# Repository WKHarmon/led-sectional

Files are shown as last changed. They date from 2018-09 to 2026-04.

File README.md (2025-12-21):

# LED Sectional

A WiFi-connected LED display for aviation sectional maps that shows real-time flight conditions at airports using color-coded LEDs.

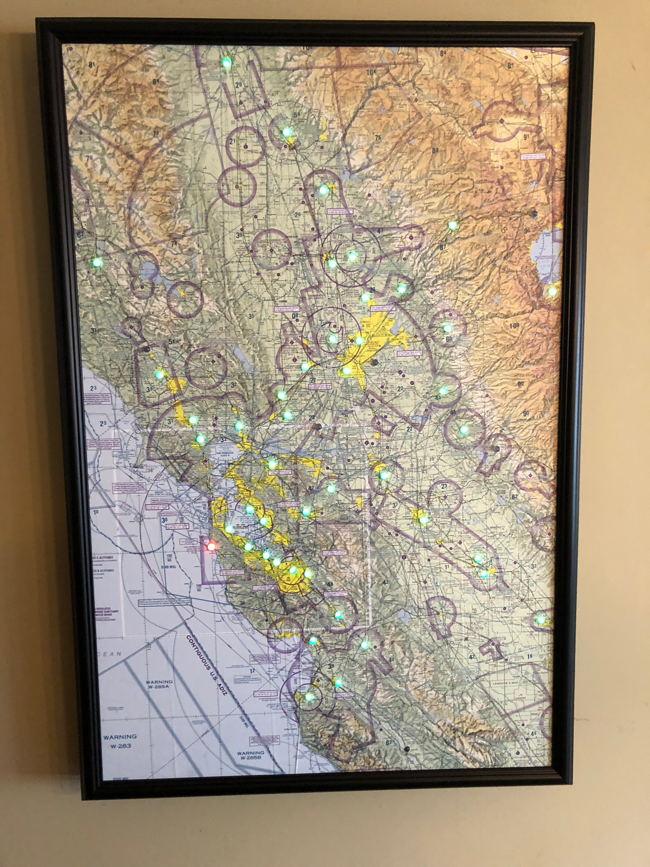
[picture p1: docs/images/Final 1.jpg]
LED Sectional Example


## What It Does

The LED Sectional automatically fetches current weather data (METARs) from aviationweather.gov and displays flight conditions on your sectional map:

| Color | Meaning |
|---|---|
| Green | VFR - Clear skies, good visibility |
| Blue | MVFR - Marginal conditions |
| Red | IFR - Instrument conditions |
| Magenta | LIFR - Low IFR, poor conditions |
| Yellow | High Winds - VFR with winds over 25 knots |
| White Flash | Thunderstorms reported |
| Off | No data available |

Weather updates automatically every 15 minutes.

## What You Need

### Hardware

- **Controller board** - ESP8266-based (Wemos D1 Mini Lite recommended), or purchase a [pre-made kit](docs/kit.md)
- **LED string** - WS2811 or WS2812 LEDs (one per airport)
- **Power supply** - 5V DC, sized for your LED count
- **USB cable** - For initial setup (must support data, not charge-only)

### Your Map

You'll need a framed sectional chart with holes drilled at each airport location. See the [full build guide](docs/index.md) for detailed instructions on creating your map.

## Setup

### Step 1: Install the Firmware

1. Visit the [LED Sectional Configuration Tool](https://led-sectional.kyleharmon.com/configure/)
2. Connect your controller via USB
3. Click the **Firmware** tab
4. Click **Install Firmware** and follow the prompts

### Step 2: Connect to WiFi

After installing firmware, the controller needs your WiFi credentials:

1. Keep the USB cable connected
2. In the Configuration Tool, click **Connect**
3. Go to the **WiFi** tab
4. Enter your network name and password
5. Click **Save** - the device will reboot and connect

**Note:** The controller only works with 2.4 GHz WiFi networks.

### Step 3: Add Your Airports

1. In the Configuration Tool, go to the **Airports** tab
2. Add airports in order matching your LED string (LED 1 first, LED 2 second, etc.)
3. Use standard ICAO codes (e.g., KSFO, KJFK, KORD)
4. Click **Save** to upload to the device

**Special codes:**
- `NULL` - Skip an LED (leave it off)
- `VFR`, `MVFR`, `IFR`, `LIFR`, `WVFR` - Legend LEDs that always show that color
- `WBNK` - Wind blink demo - alternates between green and yellow (requires "Alternate Colors" setting enabled)

### Step 4: Mount and Enjoy

Disconnect USB, connect your 5V power supply, and mount your sectional!

## Troubleshooting

### LEDs aren't lighting up

- Check that your power supply is 5V and has enough current for your LED count
- Verify the data wire is connected to the correct pin (GPIO 14 / D5 by default)
- Make sure the LED string and controller share a common ground

### Can't connect via Web Serial

- Use Chrome, Edge, or Opera (Safari and Firefox don't support Web Serial)
- Try a different USB cable - some cables only carry power, not data
- Close any other programs that might be using the serial port

### WiFi won't connect

- Confirm your network is 2.4 GHz (5 GHz is not supported)
- Double-check the password
- Move the controller closer to your router during setup

### Some airports show no color

- The airport may not have recent METAR data
- Verify the ICAO code is correct at [aviationweather.gov](https://aviationweather.gov/)

## Adjusting Settings

In the Configuration Tool's **Settings** tab, you can adjust:

- **Brightness** - LED brightness level (0-255)
- **Wind Threshold** - Wind speed that triggers yellow color (default: 25 knots)
- **Lightning Animation** - Enable/disable flashing for thunderstorms
- **High Wind Indication** - Enable/disable yellow for high winds
- **Light Sensor** - Enable automatic brightness based on room lighting (requires additional hardware)

### Home Assistant Integration

The LED Sectional can integrate with Home Assistant for smart home control. Once configured, your sectional appears as a light in Home Assistant where you can:

- Turn the display on/off
- Adjust brightness
- Include in automations (e.g., dim at night, turn off when away)

To set up, go to **Settings > Advanced Settings** in the Configuration Tool and enable MQTT. Enter your Home Assistant's MQTT broker address and credentials. The device will automatically appear in Home Assistant via MQTT Discovery.

## More Information

- [Full Build Guide](docs/index.md) - Detailed instructions for building your sectional
- [Kit Information](docs/kit.md) - Pre-made electronics kit
- [Contributing & Development](CONTRIBUTING.md) - For developers who want to modify the code

## Acknowledgments

- Inspired by [this Reddit post](https://www.reddit.com/r/flying/comments/7avr8q/flight_conditions_sectional_wall_art_thing/) and [Dylan Rush's blog](http://blog.dylanhrush.com/2017/07/live-sectional-map.html)
- Weather data from [aviationweather.gov](https://aviationweather.gov/)
- Web flashing powered by [ESP Web Tools](https://esphome.github.io/esp-web-tools/)

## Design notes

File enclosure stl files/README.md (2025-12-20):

# LED Sectional Enclosure
These are STL files used to 3D print a small enclosure for the [PCB used in this project](https://github.com/WKHarmon/led-sectional/tree/main/pcb%20files). The board is attached to the enclosure using 3 short M2 screws.

I've published this on Seeed Studio's [Fusion Gallery](https://www.seeedstudio.com/LED-Sectional-Board-g-1207811) for easy making.

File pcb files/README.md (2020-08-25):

# PCB Files
Originally this project used a WEMOS D1 Mini; however, to make assembly a bit easier the PCB now has all the components placed on the PCB directly, including an ESP8285 microcontroller. All of the SMD components are from the parts library that [jlcpcb.com](https://jlcpcb.com) can assemble directly for cheap. The files in this folder are:

* LED Sectional PCB - EasyEDA.json - PCB design file for import into EasyEDA.
* LED Sectional - Gerbers.zip - PCB production files that should be usable by any PCB manufacturer.
* LED Sectional - BOM.csv - All of the components used in the board design.
* LED Sectional - Centroid.csv - Pick and place file for assembly of the SMD components.

If assembling through jlcpcb.com, it's still necessary to solder all of the through hole components like the micro USB, power, and LED connectors. Other assembly fabs can handle the thru-hole components, but most charge significantly more for the via-in-pads that are used in the design.

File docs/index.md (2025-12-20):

LED Sectional
=============
* [LED Sectional](#led-sectional)
* [Pictures](#pictures)
* [Things you'll need](#things-youll-need)
    * [Electronics](#electronics)
        * [LED Sectional Kit](#led-sectional-kit)
        * [Buying a la carte](#buying-a-la-carte)
    * [Map and Frame](#map-and-frame)
    * [Tools](#tools)
* [Software](#software)
* [Assembly](#assembly)
    * [Soldering and Wiring](#soldering-and-wiring)
    * [Mounting the sectionals](#mounting-the-sectionals)
    * [Drilling](#drilling)
    * [Glueing LEDs](#glueing-leds)
* [Final Details](#final-details)

This project is adapted from a few other very similar ones:
* [Live sectional map](http://blog.dylanhrush.com/2017/07/live-sectional-map.html)
* [Flight conditions sectional wall art thing](https://www.reddit.com/r/flying/comments/7avr8q/flight_conditions_sectional_wall_art_thing/)
* [Creating a METAR map](https://pplaviationuk.wordpress.com/creating-a-metar-map/)

There were small gaps in the how-to details for some of them so I figured it might be helpful to fully document how I did it. I also opted to use a microcontroller rather than a Raspberry Pi, so mine is different in that way too.

# Pictures
Here are a few pictures of the final product:
Final Product
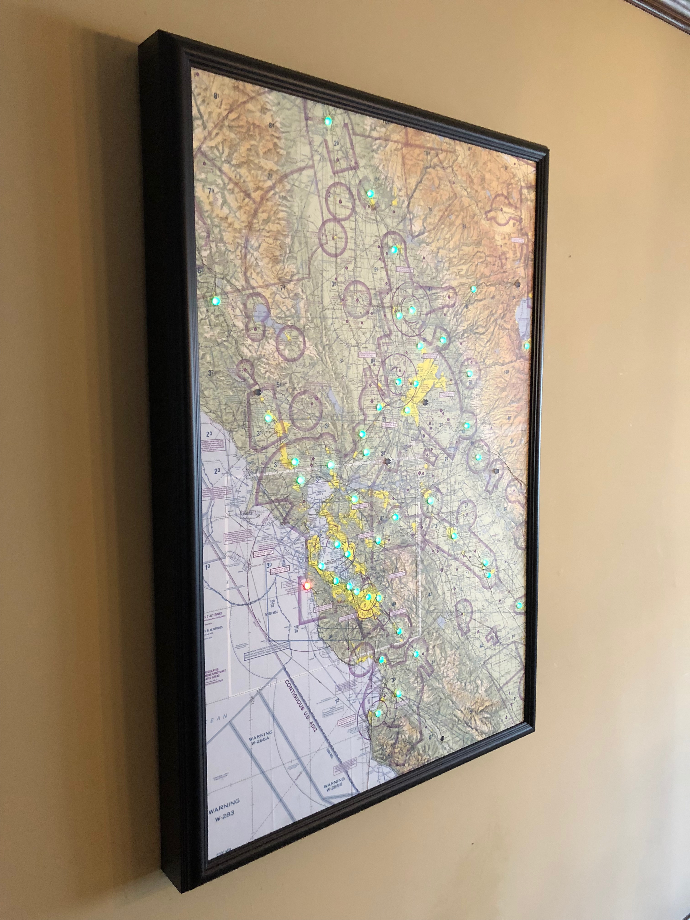
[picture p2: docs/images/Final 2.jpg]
Final Product

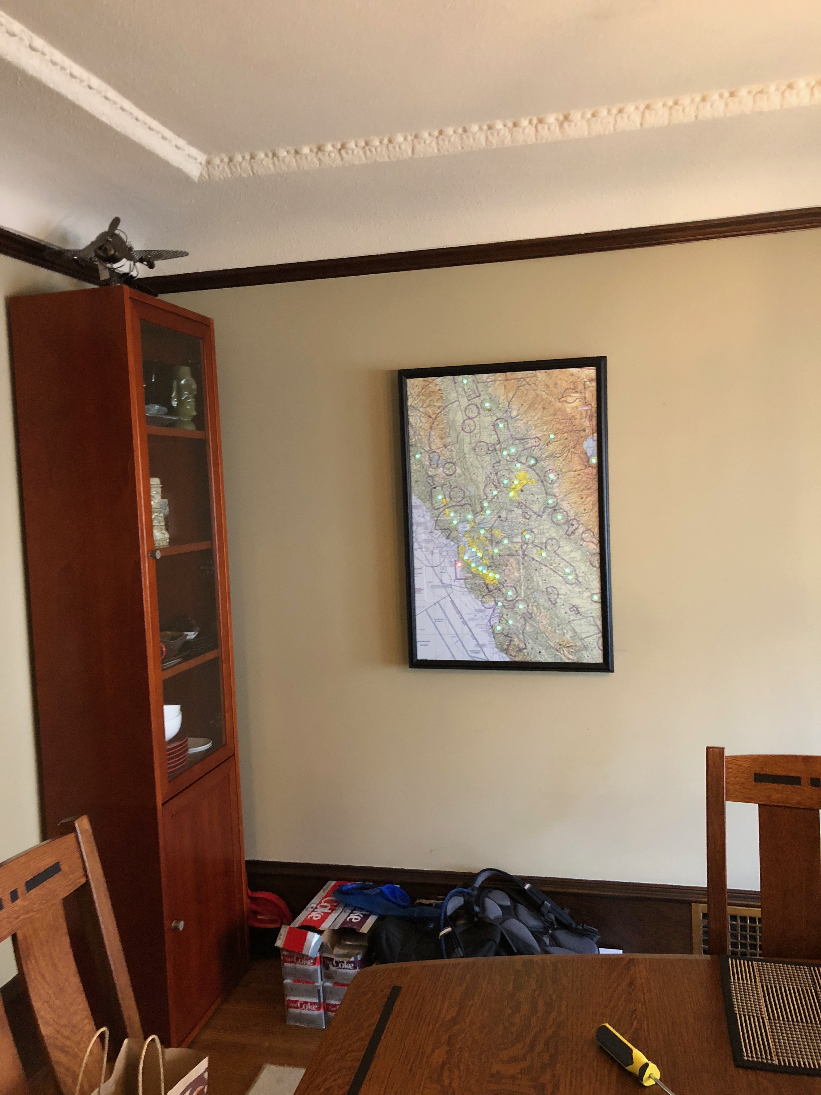
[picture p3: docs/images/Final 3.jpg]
Final Product


# Things you'll need
The materials themselves are pretty cheap--you should be able to get everything you need aside from the frame for less than $100. The frame cost will vary depending on how big you want to make the sectional. The tools may add some cost if you don't already have what you need.

## Electronics
### LED Sectional Kit
I originally wrote this guide with instructions on how to buy all of the electronic components on Amazon, but now I have a kit available that contains all of the electronics except for the power adapter and the LED strands themslves. The kit is significantly cheaper than buying each of the components a la carte since most of the components come in large quantities.

[Click here to find out more information about the kit.](kit.md)

The Amazon links from the original how-to are below in case you'd enjoy doing everything yourself.

### Buying a la carte
I've linked to Amazon for most of the electronic items. You should be able to buy them for cheaper and in smaller quantites from Aliexpress or another similar store if you're willing to wait for the shipment. (In the interest of full disclosure, the Amazon links do have my affiliate tags, but I'm not really trying to make any money here.)
* [WEMOS D1 Mini Lite](https://www.aliexpress.com/store/product/WEMOS-D1-mini-Lite-V1-0-0-WIFI-Internet-of-Things-development-board-based-ESP8285-1MB/1331105_32795857574.html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)
    * If you have time to wait for the shipment, support them and buy from the official store, but [this version on Amazon](https://amzn.to/2R4Pjio) also worked fine.
    * The non-Lite version will work fine, and this code should be pretty adaptable to any Arduino-compatible board with WiFi.
* 3.3V to 5V Level Shifter
    * [WeiMeet 4 Channel Level Converter](https://amzn.to/2R50OGu) - These are what I originally used (and will document here), but they're considered to be a bit slow. You may run into problems if you have a ton of LEDs.
    * [74HCT245](https://www.aliexpress.com/item/10PCS-SN74HCT245N-DIP20-SN74HCT245-DIP-74HCT245-74HCT245N-DIP-20-new-and-original-IC/32537892034.html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) are faster and are what I use in the kit.
* [WS2811 LED Strand(s)](https://amzn.to/2BsGVzj)
* [5V DC Power Supply](https://amzn.to/2EE5Oft) - This is more power than you really need--you could get a smaller one if you'd prefer.
* [DC Barrel Connectors](https://amzn.to/2Gu7aeh)
* [Solid Core Hookup Wire](https://amzn.to/2BwFLD3) - 22G worked well for me
* [3cm x 7cm PCB](https://amzn.to/2GudB15) - This has a bunch of PCBs, I'm sure there's a cheaper opton. Other sizes will work, but these fit nicely into a small project enclosure.
* Optional: [80mm x 50mm x 20mm Project Enclosure](https://amzn.to/2ShrLUw)
* Optional: 3-pin [JST-XH Connectors](https://amzn.to/2SbjpOi) and [JST-SM Connectors](https://amzn.to/2LoXkJy) if you want a interface between the microcontroller and the LED strand(s)
* Optional: [Velcro](https://amzn.to/2BssRpr) to affix the power supply and controller to the board
* Optional components recommended by NeoPixels that I didn't add:
    * 1000 µF, 6.3V or higher capacitor - put this between the 5v and Ground on the power adapter to mitigate spikes on power-on
    * 220 Ohm resistor - put this on the data wire between the level shifter HV1 pin and the data wire on the connector to the LED strand to also mitigate power spikes

## Map and Frame
**You'll also need either:**
* Sectional(s) from the FAA - remember that they're two sided so you may need two to get full coverage
* 3/8" Foamcore or [Hard Tempered Board](https://www.homedepot.com/p/Hardboard-Tempered-Common-1-8-in-x-2-ft-x-4-ft-Actual-0-125-in-x-23-75-in-x-47-75-in-7005015/202088786) or MDF
    * I used the board in my first map, but found foamcore to be much easier to work with on one I made for a friend.
* [3M Super 77 Spray Adhesive](https://www.homedepot.com/p/3M-16-7-oz-Super-77-Multi-Purpose-Spray-Adhesive-77-24VOC30/301619194)
* [SP8 Picture Frame](https://www.pictureframes.com/Custom-Frames/Canvas-Ready-Wood-Picture-Frames/SP8-black-wood-canvas-frame)
    * This is one of the only super-deep frames I've seen that are easily orderable online.
* Optional: [PVA Adhesive](https://amzn.to/2EC5qhn) if you have a seam between sectionals

**OR**

* Have a [digital file](https://www.faa.gov/air_traffic/flight_info/aeronav/digital_products/vfr/) of the sectional printed and mounted on foamcore at [PictureFrames.com](http://www.pictureframes.com). If you do this, be sure to maintain the 300 ppi from the original file in order to keep the sectional to scale (assuming you want that at least).
    * Use the [SP8 Picture Frame](https://www.pictureframes.com/Custom-Frames/Canvas-Ready-Wood-Picture-Frames/SP8-black-wood-canvas-frame) for plenty of depth. The [SP2 Picture Frame](https://www.pictureframes.com/Custom-Frames/Canvas-Ready-Wood-Picture-Frames/SP2-black-wood-canvas-frame) also works pretty well, but the wires may rub against the wall.

## Tools
Here are the tools you'll need. I've provided links to the ones I use, but any set of good tools will work.
* [Glue gun](https://amzn.to/2V492Om) with plenty of [glue](https://amzn.to/2Sby6RA)

If you used foamcore backing:
* [Foamboard Hole Drill](https://amzn.to/2VIc7Du) (You'll use the smallest one in the set.)

If you used wood backing:
* Drill with a 7mm drill bit

If you went the a la carte route for the electronics, you'll also need:
* [Soldering iron](https://amzn.to/2BwFUGB) and solder
* [Wire stripper](https://amzn.to/2BzBWg6)
* Optional: [Crimper for JST connectors](https://amzn.to/2S5a1fi)

# Software

## Web-Based Configuration (Recommended)

The easiest way to set up your LED Sectional is using the **[LED Sectional Configuration Tool](configure/)**. This browser-based tool allows you to:

* **Flash firmware** directly from your browser - no software installation required
* **Configure WiFi** by entering your network credentials
* **Set up your airport list** with a drag-and-drop interface
* **Adjust settings** like brightness, wind thresholds, and lightning effects
* **Connect to Home Assistant** for smart home control (optional)

Just connect your controller via USB, open the tool in Chrome, Edge, or Opera, and follow the on-screen instructions.

## How It Works

The program uses standard definitions for VFR, MVFR, IFR, and LIFR, but also shows yellow if an airport is VFR with winds greater than 25 knots, and airports will flash white if there are thunderstorms in the area.

On power on, all LEDs will show orange initially. Once the controller is connected to the WiFi network, they'll turn purple, and then they'll show the airport colors once the data is downloaded and parsed. LEDs for airports that have not reported weather in the last 3 hours, or that don't have a clear flight category will be turned off. Weather is updated every 5 minutes.

## Manual Setup (Advanced)

If you prefer to program the board manually, the source code is available at [https://github.com/WKHarmon/led-sectional](https://github.com/WKHarmon/led-sectional). See the [CONTRIBUTING.md](https://github.com/WKHarmon/led-sectional/blob/main/CONTRIBUTING.md) file for development instructions.

# Assembly
## Soldering and Wiring
The following section is only necessary if you went the a la carte route.

The Wemos D1 Mini Lite can accept 5V as input voltage, but the GPIO pins run at 3.3v. The WS2811 LED strand is expecting 5V on the data line, so it is necessary to convert the GPIO 3.3v to the WS2811 5V using a logic level shifter. (In some cases it may work without the shifter, but using one is the safer bet.) Below is a breadboard diagram for wiring it all up:

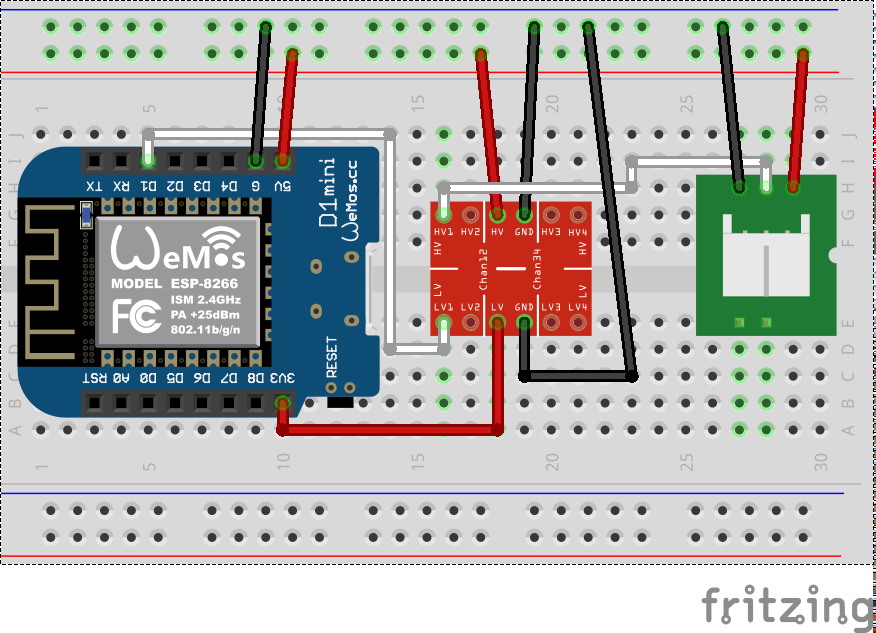
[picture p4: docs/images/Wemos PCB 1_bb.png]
Breadboard Diagram


I've diagramed on a breadboard for simplicity, but I used a 3cm x 7cm PCB. In the diagram, the (optional) JST-XH connector on the right goes to the WS2811 LED strand. If you don't want to bother with the connector, you can just solder the wires from the LED strand to the PCB.

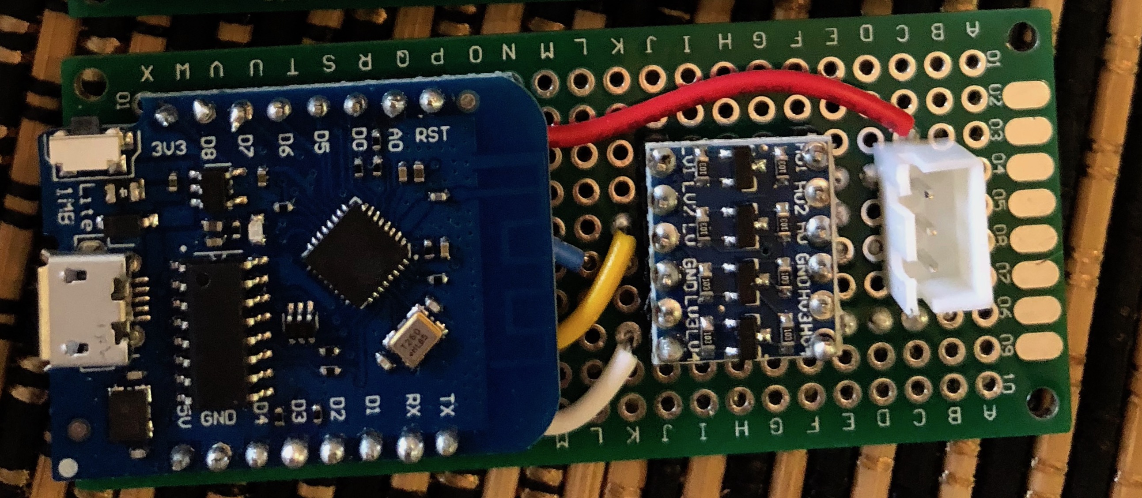
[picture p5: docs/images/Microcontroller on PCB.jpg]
Controller on PCB


 If you have a smaller number of LEDs on your map, it may be possible to power the LED strand from the Micro USB port on the Wemos D1 Mini rather than connecting an external power supply. No wiring changes are necessary, but be sure to not connect an external power supply when the Micro USB port is connected. Also be aware that the Wemos D1 Mini has a 0.5A fuse on the 5V line so it would need to be a really small number of LEDs.	

The data flow on the WS2811 strand is directional. In the LED pixel itself, the PCB will be marked with an arrow on one side. That arrow indicates the input side of the pixel. Connect the microcontroller to the side of the strand such that the wires from the controller are connected to the input side of the pixel (with the arrow), matching the 5V, Data, and Ground lines on the strand to those on the controller.

The WS2811 LED strand has pigtails for injecting power on the ends of the strand as well. Solder a DC barrel connector for power to the pigtails nearest the microcontroller. The microcontroller will receive power from its conenction to the LED strand.

Once I had it all connected up, I created a small pigtail with a JST-XH connector on one side and a JST-SM connector on the other side (which matches the connectors that came with the LED strand) to make it easy to attach and detach the LED strand, then I put it in an enclosure box.

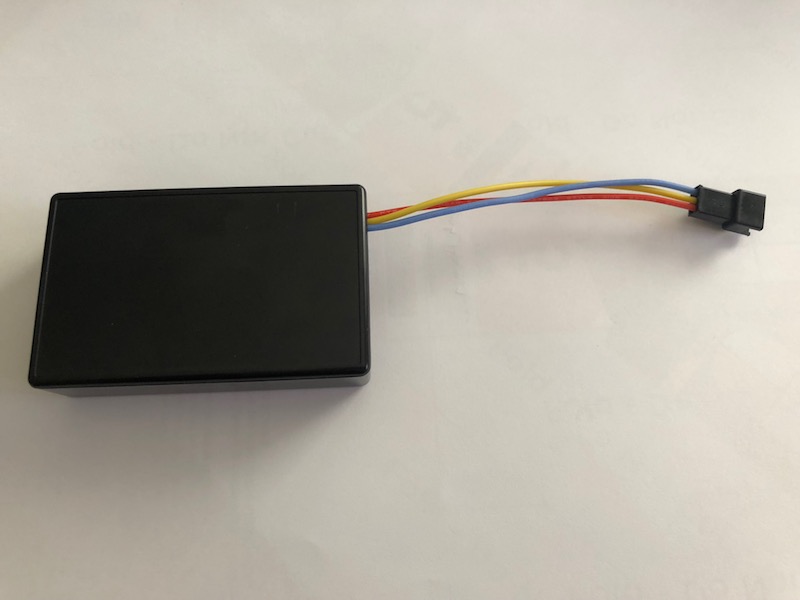
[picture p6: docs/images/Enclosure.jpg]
Enclosure


## Mounting the sectionals
This section is only necessary if you bought actual sectionals and didn't take the shortcut and have a sectional printed and pre-mounted.

When I bought the Hard Tempered Board noted above, I had Home Depot cut it to the desired size. The combined halves of the San Francisco sectional were just over 36" high, and the board itself was 24" wide, so I just decided to use that width.

I cut off the bottom white space of the northern sectional, then I taped the sectionals at the seam using scotch tape, and measured which 24" of the sectional width I actually wanted. I then put the board on top of the sectional and used an Exacto knife to cut off the excess parts of the sectional, but leaving about 1" on each side of the sectional just in case I didn't get it perfectly centered when glueing.

Next, I sprayed the shiny side of the board with the 3M Spray Adhesive, waited about a minute per the directions, and then laid the sectional flat on the board so it would adhere. I used a ruler to flatten out any spots that were not flat.

Once the glue was dried, I cut off the excess parts of the sectional using an exacto knife, and then glued the flap created by the seam between the two sectionals using PVA Adhesive.

## Drilling
**Important: Don't use ForeFlight to determine where METARs are available.** ForeFlight aggregates several sources of weather data together, and contains several airports that are not available via the aviationweather.gov API. I suggest using the METAR map at aviationweather.gov to determine where to drill.

The Foamboard Holl Drill makes super clean cuts and is the perfect size for the LEDs, so I highly recommend grabbing that set if you used foamcore backing and drilling using them.

On my first board I used wood backing, which was quite a bit more challenging. I used a 7mm drill bit to drill through the sectional and the backing board together. This resulted in some holes that weren't super clean.

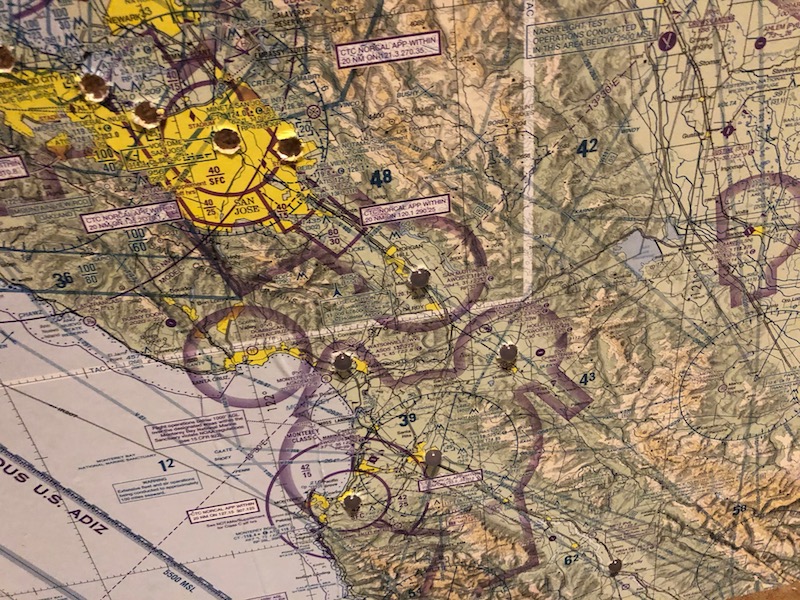
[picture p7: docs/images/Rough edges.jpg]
Rough Edges


I specifically wanted my LEDs to stick out, but if you don't then adjusting the drill bit size and using a countersink bit would allow you to align them with the front of the board.

After I drilled, I then took a file and an exacto knife to clean up the edges to make it look significantly better.

## Glueing LEDs
Once all of the holes were drilled, I rough fit the LEDs throught he holes in the back to try to find the optimal routing. IT's not important what order they're in yet--I'm just trying to waste the fewest LEDs. Once I figured it out, I started gluing a few at a time using the hot glue gun.

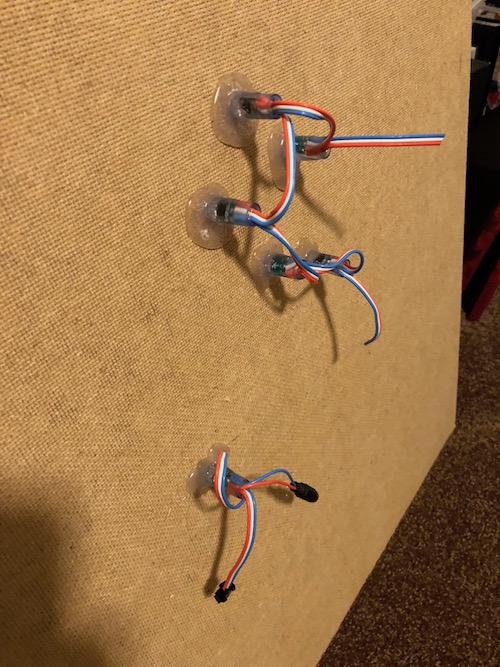
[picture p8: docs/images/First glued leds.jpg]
First Glued LEDs


In the picture you can see that I cut the strand because the next LED in the strand was too far from the previous one, but eventually I realized that LEDs are cheap, so it is much easier to just leave the LEDs on the strand and not use them than to cut the strand and splice in a jumper. The final product looked like this:

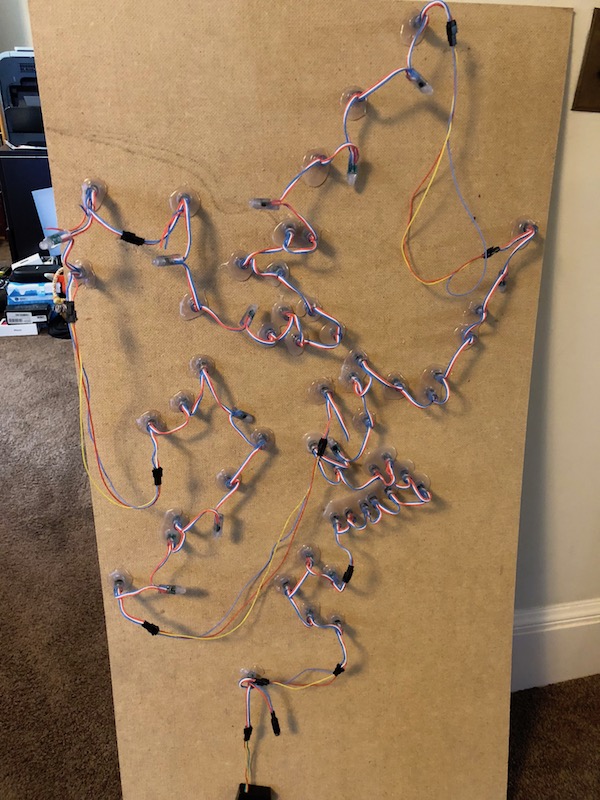
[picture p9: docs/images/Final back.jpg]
Final Back


# Final Details
Because I don't have good tools or really any skills with woodworking, I purchased a frame from [http://www.pictureframes.com](https://www.pictureframes.com/Custom-Frames/Canvas-Ready-Wood-Picture-Frames/SP8-black-wood-canvas-frame). Their SP8 frame has 2 1/4" of depth, which is plenty to contain the electronics. For my 24"x36 1/2" project, it cost me about $120 shipped for the frame, and it came fully assembled with mounting hardware (but no glass), which I thought was a pretty good details.

I mounted the map on a place on my wall previously had a wall sconce light, so I was able to re-use the existing power rather than running new power or running a cable.

Enjoy!

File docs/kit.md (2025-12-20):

# LED Sectional Kits
On the [/r/flying subreddit](https://www.reddit.com/r/flying) there was a [great deal of interest](https://www.reddit.com/r/flying/comments/a4yb83/aviation_nerd_jackpot/ebiscca/) in a simple kit for the electronic components that could be used to create a [LED Sectional](index.md). Because of that, I've created a simple kit to help kickstart the process.

## Ordering

There are three different ordering links depending on how you'd like your kit configured.
1. [Buyer programs](https://www.paypal.com/cgi-bin/webscr?cmd=_s-xclick&hosted_button_id=CFKGLG5F2ETDW)
    * The kit will arrived programmed with a LED test program so you can ensure the strand is working properly. You'll need to program it for your map using the instructions located [here](index.md#software). You will need a high-quality Micro USB cable in order to program the board.
2. [Buyer programs, with an included ambient light sensor](https://www.paypal.com/cgi-bin/webscr?cmd=_s-xclick&hosted_button_id=67RASVCG8DK5A)
    * This includes an added ambient light sensor so the map can be programmed to automatically turn off when the ambient lights are off. I would recommend ONLY adding the light sensor if you plan to put the map in a room where the light will be disruptive at night as this will not significantly impact power usage.

**An important note:** *These kits are provided without support.* If there are any hardware problems with the kit you receive please reach out and I'll be happy to help, but you should only buy it if you're comfortable with the instructions and troubleshooting on your own. I'm not trying to make a profit on these so I am selling these very close to cost. As you can imagine, there's a fair bit of effort involved in putting them together. If you like your kit once you receive it, I would appreciate it if you considered giving a tax deductible donation to the [Upwind Foundation](https://www.upwindscholarship.com/). We're having a bit of a contest to see who can raise the most, so please do mention my name (Kyle Harmon) if you donate.

## About the Kit
The kit includes the following:
* A custom PCB that includes the following:
    * An ESP8285 microcontroller and components and interfaces that replicate a [WEMOS D1 Mini Lite](https://docs.wemos.cc/en/latest/d1/d1_mini_lite.html) development board.
    * The following additional components included for connectivity and to comply with [Adafruit's Best Practices](https://learn.adafruit.com/adafruit-neopixel-uberguide/best-practices):
        * [330 Ohm Resistor](https://lcsc.com/product-detail/Chip-Resistor-Surface-Mount_UNI-ROYAL-Uniroyal-Elec-0603WAF3300T5E_C23138.html)
        * [1000 µF Capacitor](https://lcsc.com/product-detail/Aluminum-Electrolytic-Capacitors-SMD_Lelon-VEJ102M1ATR-1010_C134756.html)
        * [3-pin JST XH Connector](https://lcsc.com/product-detail/Wire-To-Board-Wire-To-Wire-Connector_BOOMELE-Boom-Precision-Elec-XH-3A_C2316.html) to connect LEDs
        * [5-pin JST XH Connector](https://lcsc.com/product-detail/Wire-To-Board-Wire-To-Wire-Connector_BOOMELE-Boom-Precision-Elec-XH-5A_C2318.html) (if shipped with a light sensor) connected to the i2c bus for a TSL2561 light sensor
        * 2x [TS-1187A-B-A-B tacticle switches](https://lcsc.com/product-detail/Tactile-Switches_XKB-Connectivity-TS-1187A-B-A-B_C318884.html), one connected to the reset switch and one ("PROGRAM") connected to GPIO12 (currently unused in the sketch)
        * [M74VHC1GT126DF1G logic level shifter](https://lcsc.com/product-detail/Logic-Buffers-Drivers-Receivers-Transceivers_ON-Semiconductor-ON-M74VHC1GT126DF1G_C150237.html) to shift 3.3v logic to 5v logic for LEDs
        * [2.1mm x 5.5mm DC Barrel Jack](https://www.digikey.com/product-detail/en/cui-inc/PJ-037A/CP-037A-ND/1644545)
* Custom 3D printed case
* JST-XH to JST-SM cable for connecting LEDs.

Here's are some pictures of what you get:
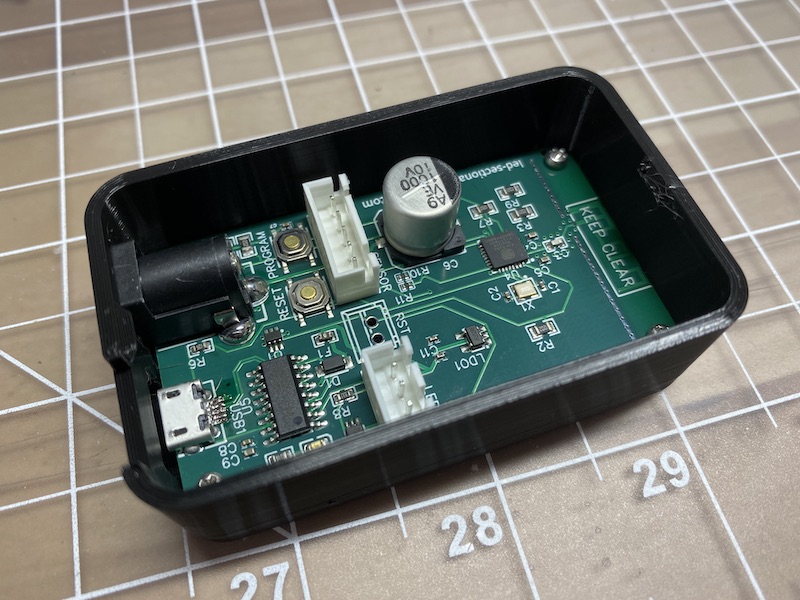
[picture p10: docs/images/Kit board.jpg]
Kit board

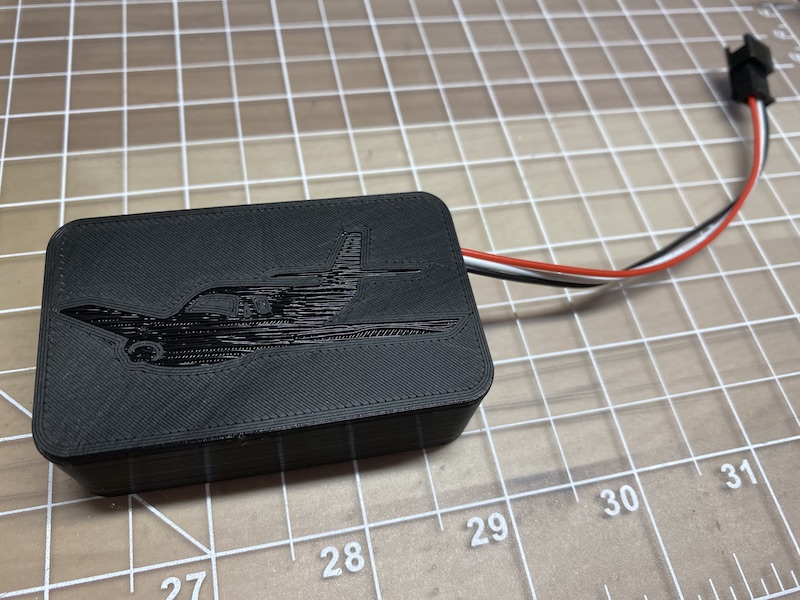
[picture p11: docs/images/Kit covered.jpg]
Kit covered


For the electronics, you'll need to purchase the following items as well:
* [WS2811 LED Strands](https://amzn.to/2Sng8vF) (choose the 5V version)
* [5V Power Supply](https://amzn.to/2RnCvn8)

You'll also need to purchase sectionals, backing, glue, etc. to create and mount the map itself. The details about how I did that are documented [here](index.md).

## Using the Kit

The easiest way to set up your kit is using the **[LED Sectional Configuration Tool](configure/)**. This browser-based tool allows you to flash firmware, configure WiFi, and set up your airport list - all without installing any software.

For more details, see the [full software instructions](index.md#software).

## Limitations
There are a couple of limitations to note:
* This is still a DIY project. I’m trying to make it pretty polished, but it’ll be a little rough around the edges. The color of the case and the board may change.
* The kit only supports 2.4 GHz WiFi, and you should ensure that you have a solid signal wherever you plan to put the map.
* I’ve tested this to about 100 LEDs. It shouldn’t have much trouble handling any single sectional, but if you plan to use a much larger area let me know so I can test it ahead of time.

## Open Source
Everything about the kit is open source. The firmware and web configuration tool source code is available on [GitHub](https://github.com/WKHarmon/led-sectional). If you'd like to make your own PCB, the Eagle files are in the [pcb files](https://github.com/WKHarmon/led-sectional/tree/main/pcb%20files) folder, and if you have a 3D Printer the STL files for the enclosure are in the [enclosure stl files](https://github.com/WKHarmon/led-sectional/tree/main/enclosure%20stl%20files) folder.

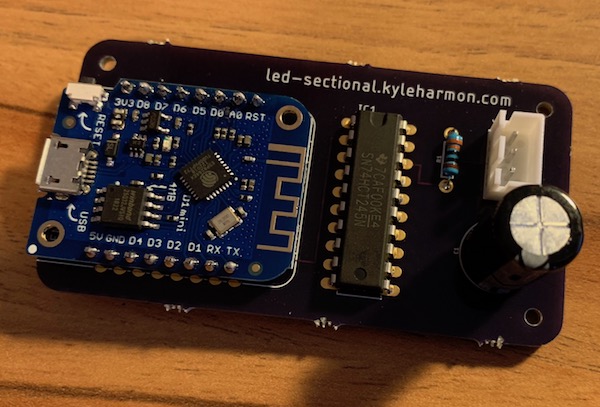
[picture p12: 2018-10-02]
docs/images/PCB.jpg

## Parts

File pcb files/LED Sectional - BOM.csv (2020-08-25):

ID | Name | Designator | Footprint | Quantity | Manufacturer Part | Manufacturer | Supplier | Supplier Part | LCSC Assembly
1 | 1000uF | C6 | CAP-SMD_BD10.0-L10.3-W10.3-RD | 1 | VEJ102M1ATR-1010 | LELON | LCSC | C134756 | Yes
2 | 2.1MMJACK | U6 | PJ-102A | 1
3 | SMD0603-050 | F1 | 0603 | 1 | SMD0603-050 | TECHFUSE | LCSC | C69679 | Yes
4 | UMH3N | Q1 | SC-70-6(SOT-363) | 1 | UMH3N | CJ | LCSC | C62892 | Yes
5 | 26MHz | X1 | OSC-SMD_4P-L2.5-W2.0-BL | 1 | X2B026000B91H-HZ | Harmony Elec | LCSC | C136060 | Yes
6 | CH340C | U5 | SOP-16_L10.0-W3.9-P1.27-LS6.0-BL | 1 | CH340C | WCH | LCSC | C84681 | Yes
7 | 12K | R1,R2,R3,R7,R4,R9 | 0805 | 6 | 0805W8F1202T5E | UniOhm | LCSC | C17444 | Yes
8 | ME6211C33M5G-N | LDO1 | SOT-23-5 | 1 | ME6211C33M5G-N | MICRONE | LCSC | C82942 | Yes
9 | XH-5A | SENSOR | CONN-TH_5P-P2.50_XH-5A_C2318 | 1 | XH-5A | BOOMELE | LCSC | C2318
10 | M74VHC1GT126DF1G | U2 | SOT-353_L2.2-W1.4-P0.65-LS2.4-BL | 1 | M74VHC1GT126DF1G | ON Semicon | LCSC | C150237 | Yes
11 | micro USBFemale | USB1 | MICRO-USB-SMD_5P-P0.65-H-F_C10418 | 1 | micro USBFemale | ValuePro | LCSC | C10418
12 | XH-3A | LEDS | XH-3A | 1 | XH-3A | BOOMELE | LCSC | C2316
13 | TS-1187A-B-A-B | PROGRAM,RESET | SW-SMD_4P-L5.1-W5.1-P3.70-LS6.4 | 2 | TS-1187A-B-A-B | XKB Enterprise | LCSC | C318884 | Yes
14 | 100 | R5 | R0603 | 1 | 0603WAF1000T5E | UniOhm | LCSC | C22775 | Yes
15 | 5.6pF | C3 | 0603 | 1 | 0603N5R6C500 | Huaxin S&T | LCSC | C123584 | Yes
16 | 10pF | C1,C2 | 0402 | 2 | CL05C100JB5NNNC | SAMSUNG | LCSC | C32949 | Yes
17 | 19-217/BHC-ZL1M2RY/3T | LED1 | LED0603-R-RD | 1 | 19-217/BHC-ZL1M2RY/3T | EVERLIGHT | LCSC | C72041 | Yes
18 | 10uF | C4,C5,C9 | 0402 | 3 | CL05A106MQ5NUNC | SAMSUNG | LCSC | C15525 | Yes
19 | 4.7K | R10,R11 | R0402 | 2 | 0402WGF4701TCE | UniOhm | LCSC | C25900 | Yes
20 | 1uF | C10,C11 | 0402 | 2 | CL05A105KA5NQNC | SAMSUNG | LCSC | C52923 | Yes
21 | 100nF | C8,C13,C7 | 0402 | 3 | CL05B104KO5NNNC | SAMSUNG | LCSC | C1525 | Yes
22 | AN043 | U1 | AN043-PCB | 1
23 | XH-2A | RST | XH-2A | 1 | XH-2A | BOOMELE | LCSC | C20079
24 | 2.4GHz | U4 | QFN-32_L5.0-W5.0-P0.50-TL-EP | 1 | ESP8285 | ESPRESSIF | LCSC | C83901 | Yes
25 | 470 | R6 | 0603 | 1 | 0603WAF4700T5E | UniOhm | LCSC | C23179 | Yes
26 | B5819W_C8598 | D1 | SOD-123_L2.8-W1.8-LS3.7-RD | 1 | B5819W | CJ | LCSC | C8598 | Yes
27 | 330 | R8 | 0603 | 1 | 0603WAF3300T5E | UniOhm | LCSC | C23138 | Yes

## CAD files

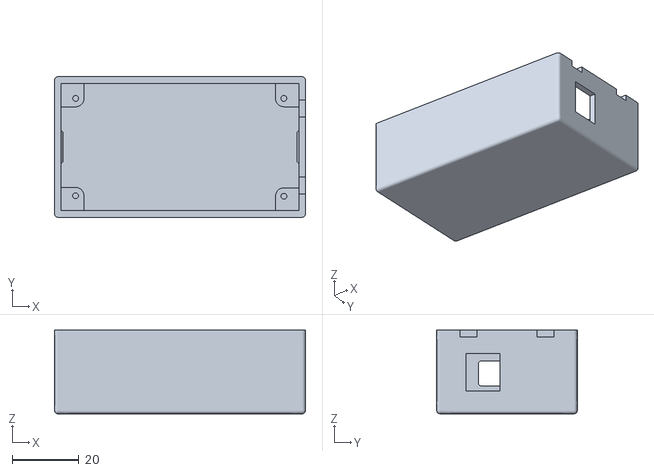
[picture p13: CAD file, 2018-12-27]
enclosure stl files/LED Sectional Body.stl
75.0 x 42.0 x 25.0

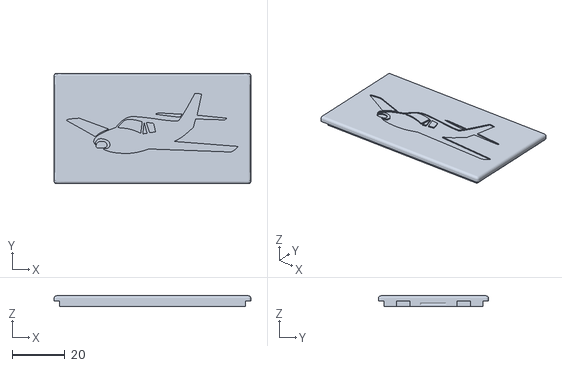
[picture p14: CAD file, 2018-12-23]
enclosure stl files/LED Sectional Cover.stl
75.0 x 42.0 x 4.00

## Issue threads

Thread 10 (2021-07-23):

First LED not correct color

Aschaff21, 2021-07-23:
I'm having issues with my first LED not showing the correct color. It always shows LIFR basically a purple color. Any ideas? I've attached my code and some pictures. any help would be great!

#include <ESP8266WiFi.h>
#include <FastLED.h>
#include <vector>
using namespace std;

#define FASTLED_ESP8266_RAW_PIN_ORDER

#define NUM_AIRPORTS 30 // This is really the number of LEDs
#define WIND_THRESHOLD 25 // Maximum windspeed for green, otherwise the LED turns yellow
#define LOOP_INTERVAL 5000 // ms - interval between brightness updates and lightning strikes
#define DO_LIGHTNING true // Lightning uses more power, but is cool.
#define DO_WINDS true // color LEDs for high winds
#define REQUEST_INTERVAL 900000 // How often we update. In practice LOOP_INTERVAL is added. In ms (15 min is 900000)

#define USE_LIGHT_SENSOR false // Set USE_LIGHT_SENSOR to true if you're using any light sensor.
// Set LIGHT_SENSOR_TSL2561 to true if you're using a TSL2561 digital light sensor.
// Kits shipped after March 1, 2019 have a digital light sensor. Setting this to false assumes an analog light sensor.
#define LIGHT_SENSOR_TSL2561 false

const char ssid[] = "SpectrumSetup-C8"; // your network SSID (name)
const char pass[] = "loudpencil884"; // your network password (use for WPA, or use as key for WEP)

// Define the array of leds
CRGB leds[NUM_AIRPORTS];
#define DATA_PIN     14 // Kits shipped after March 1, 2019 should use 14. Earlier kits us 5.
#define LED_TYPE    WS2812B
#define COLOR_ORDER GRB
#define BRIGHTNESS 20 // 20-30 recommended. If using a light sensor, this is the initial brightness on boot.

/* This section only applies if you have an ambient light sensor connected */
#if USE_LIGHT_SENSOR
/* The sketch will automatically scale the light between MIN_BRIGHTNESS and
MAX_BRIGHTNESS on the ambient light values between MIN_LIGHT and MAX_LIGHT
Set MIN_BRIGHTNESS and MAX_BRIGHTNESS to the same value to achieve a simple on/off effect. */
#define MIN_BRIGHTNESS 20 // Recommend values above 4 as colors don't show well below that
#define MAX_BRIGHTNESS 20 // Recommend values between 20 and 30

// Light values are a raw reading for analog and lux for digital
#define MIN_LIGHT 16 // Recommended default is 16 for analog and 2 for lux
#define MAX_LIGHT 30 // Recommended default is 30 to 40 for analog and 20 for lux

#if LIGHT_SENSOR_TSL2561
#include <Adafruit_Sensor.h>
#include <Adafruit_TSL2561_U.h>
#include <Wire.h>
Adafruit_TSL2561_Unified tsl = Adafruit_TSL2561_Unified(TSL2561_ADDR_FLOAT, 12345);
#else
#define LIGHTSENSORPIN A0 // A0 is the only valid pin for an analog light sensor
#endif

#endif
/* ----------------------------------------------------------------------- */

std::vector<unsigned short int> lightningLeds;
std::vector<String> airports({
  "KGGG", // 1 order of LEDs, starting with 1 should be KKIC; use VFR, WVFR, MVFR, IFR, LIFR for key; NULL for no airport
  "KTYR", // 2
  "KACT", // 3
  "KSEP", // 4
  "KBKD", // 5
  "KBKD", // 6
  "KMWL", // 7
  "KFWS", // 8
  "KRBD", // 9
  "KGVT", // 10
  "KDUA", // 11
  "KADM", // 12
  "KTKI", // 13
  "KDFW", // 14
  "KADS", // 15
  "KFTW", // 16
  "KDTO", // 17
  "KSPS", // 18
  "KLTS", // 19
  "KLTS", // 20
  "KLAW", // 21
  "KOKC", // 22
  "KWDG", // 23
  "KSWO", // 24
  "KOKM", // 25
  "KMLC", // 26
  "KRKR", // 27
  "KMEZ", // 28
  "KTXK", // 29
  "KSLR", // 30

});

#define DEBUG false

#define READ_TIMEOUT 15 // Cancel query if no data received (seconds)
#define WIFI_TIMEOUT 60 // in seconds
#define RETRY_TIMEOUT 15000 // in ms

#define SERVER "www.aviationweather.gov"
#define BASE_URI "/adds/dataserver_current/httpparam?dataSource=metars&requestType=retrieve&format=xml&hoursBeforeNow=3&mostRecentForEachStation=true&stationString="

boolean ledStatus = true; // used so leds only indicate connection status on first boot, or after failure
int loops = -1;

int status = WL_IDLE_STATUS;

void setup() {
  //Initialize serial and wait for port to open:
  Serial.begin(74880);
  //pinMode(D1, OUTPUT); //Declare Pin mode
  //while (!Serial) {
  //    ; // wait for serial port to connect. Needed for native USB
  //}

  pinMode(LED_BUILTIN, OUTPUT); // give us control of the onboard LED
  digitalWrite(LED_BUILTIN, LOW);

  #if USE_LIGHT_SENSOR
  #if LIGHT_SENSOR_TSL2561
  Wire.begin(D2, D1);
  if(!tsl.begin()) {
    /* There was a problem detecting the TSL2561 ... check your connections */
    Serial.println("Ooops, no TSL2561 detected ... Check your wiring or I2C ADDR!");
  } else {
    tsl.enableAutoRange(true);
    tsl.setIntegrationTime(TSL2561_INTEGRATIONTIME_13MS);
  }
  #else
  pinMode(LIGHTSENSORPIN, INPUT);
  #endif
  #endif

  // Initialize LEDs
  FastLED.addLeds<LED_TYPE, DATA_PIN, COLOR_ORDER>(leds, NUM_AIRPORTS).setCorrection(TypicalLEDStrip);
  FastLED.setBrightness(BRIGHTNESS);
}

#if USE_LIGHT_SENSOR
void adjustBrightness() {
  byte brightness;
  float reading;

  #if LIGHT_SENSOR_TSL2561
  sensors_event_t event;
  tsl.getEvent(&event);
  reading = event.light;
  #else
  reading = analogRead(LIGHTSENSORPIN);
  #endif

  Serial.print("Light reading: ");
  Serial.print(reading);
  Serial.print(" raw, ");

  if (reading <= MIN_LIGHT) brightness = 0;
  else if (reading >= MAX_LIGHT) brightness = MAX_BRIGHTNESS;
  else {
    // Percentage in lux range * brightness range + min brightness
    float brightness_percent = (reading - MIN_LIGHT) / (MAX_LIGHT - MIN_LIGHT);
    brightness = brightness_percent * (MAX_BRIGHTNESS - MIN_BRIGHTNESS) + MIN_BRIGHTNESS;
  }

  Serial.print(brightness);
  Serial.println(" brightness");
  FastLED.setBrightness(brightness);
  FastLED.show();
}
#endif

void loop() {
  digitalWrite(LED_BUILTIN, LOW); // on if we're awake

  #if USE_LIGHT_SENSOR
  adjustBrightness();
  #endif

  int c;
  loops++;
  Serial.print("Loop: ");
  Serial.println(loops);
  unsigned int loopThreshold = 1;
  if (DO_LIGHTNING || USE_LIGHT_SENSOR) loopThreshold = REQUEST_INTERVAL / LOOP_INTERVAL;

  // Connect to WiFi. We always want a wifi connection for the ESP8266
  if (WiFi.status() != WL_CONNECTED) {
    if (ledStatus) fill_solid(leds, NUM_AIRPORTS, CRGB::Orange); // indicate status with LEDs, but only on first run or error
    FastLED.show();
    WiFi.mode(WIFI_STA);
    WiFi.hostname("LED Sectional " + WiFi.macAddress());
    //wifi_set_sleep_type(LIGHT_SLEEP_T); // use light sleep mode for all delays
    Serial.print("WiFi connecting..");
    WiFi.begin(ssid, pass);
    // Wait up to 1 minute for connection...
    for (c = 0; (c < WIFI_TIMEOUT) && (WiFi.status() != WL_CONNECTED); c++) {
      Serial.write('.');
      delay(1000);
    }
    if (c >= WIFI_TIMEOUT) { // If it didn't connect within WIFI_TIMEOUT
      Serial.println("Failed. Will retry...");
      fill_solid(leds, NUM_AIRPORTS, CRGB::Orange);
      FastLED.show();
      ledStatus = true;
      return;
    }
    Serial.println("OK!");
    if (ledStatus) fill_solid(leds, NUM_AIRPORTS, CRGB::Purple); // indicate status with LEDs
    FastLED.show();
    ledStatus = false;
  }

  // Do some lightning
  if (DO_LIGHTNING && lightningLeds.size() > 0) {
    std::vector<CRGB> lightning(lightningLeds.size());
    for (unsigned short int i = 0; i < lightningLeds.size(); ++i) {
      unsigned short int currentLed = lightningLeds[i];
      lightning[i] = leds[currentLed]; // temporarily store original color
      leds[currentLed] = CRGB::White; // set to white briefly
      Serial.print("Lightning on LED: ");
      Serial.println(currentLed);
    }
    delay(25); // extra delay seems necessary with light sensor
    FastLED.show();
    delay(25);
    for (unsigned short int i = 0; i < lightningLeds.size(); ++i) {
      unsigned short int currentLed = lightningLeds[i];
      leds[currentLed] = lightning[i]; // restore original color
    }
    FastLED.show();
  }

  if (loops >= loopThreshold || loops == 0) {
    loops = 0;
    if (DEBUG) {
      fill_gradient_RGB(leds, NUM_AIRPORTS, CRGB::Red, CRGB::Blue); // Just let us know we're running
      FastLED.show();
    }

    Serial.println("Getting METARs ...");
    if (getMetars()) {
      Serial.println("Refreshing LEDs.");
      FastLED.show();
      if ((DO_LIGHTNING && lightningLeds.size() > 0) || USE_LIGHT_SENSOR) {
        Serial.println("There is lightning or we're using a light sensor, so no long sleep.");
        digitalWrite(LED_BUILTIN, HIGH);
        delay(LOOP_INTERVAL); // pause during the interval
      } else {
        Serial.print("No lightning; Going into sleep for: ");
        Serial.println(REQUEST_INTERVAL);
        digitalWrite(LED_BUILTIN, HIGH);
        delay(REQUEST_INTERVAL);
      }
    } else {
      digitalWrite(LED_BUILTIN, HIGH);
      delay(RETRY_TIMEOUT); // try again if unsuccessful
    }
  } else {
    digitalWrite(LED_BUILTIN, HIGH);
    delay(LOOP_INTERVAL); // pause during the interval
  }
}

bool getMetars(){
  lightningLeds.clear(); // clear out existing lightning LEDs since they're global
  fill_solid(leds, NUM_AIRPORTS, CRGB::Black); // Set everything to black just in case there is no report
  uint32_t t;
  char c;
  boolean readingAirport = false;
  boolean readingCondition = false;
  boolean readingWind = false;
  boolean readingGusts = false;
  boolean readingWxstring = false;

  std::vector<unsigned short int> led;
  String currentAirport = "";
  String currentCondition = "";
  String currentLine = "";
  String currentWind = "";
  String currentGusts = "";
  String currentWxstring = "";
  String airportString = "";
  bool firstAirport = true;
  for (int i = 0; i < NUM_AIRPORTS; i++) {
    if (airports[i] != "NULL" && airports[i] != "VFR" && airports[i] != "MVFR" && airports[i] != "WVFR" && airports[i] != "IFR" && airports[i] != "LIFR") {
      if (firstAirport) {
        firstAirport = false;
        airportString = airports[i];
      } else airportString = airportString + "," + airports[i];
    }
  }

  BearSSL::WiFiClientSecure client;
  client.setInsecure();
  Serial.println("\nStarting connection to server...");
  // if you get a connection, report back via serial:
  if (!client.connect(SERVER, 443)) {
    Serial.println("Connection failed!");
    client.stop();
    return false;
  } else {
    Serial.println("Connected ...");
    Serial.print("GET ");
    Serial.print(BASE_URI);
    Serial.print(airportString);
    Serial.println(" HTTP/1.1");
    Serial.print("Host: ");
    Serial.println(SERVER);
    Serial.println("User-Agent: LED Map Client");
    Serial.println("Connection: close");
    Serial.println();
    // Make a HTTP request, and print it to console:
    client.print("GET ");
    client.print(BASE_URI);
    client.print(airportString);
    client.println(" HTTP/1.1");
    client.print("Host: ");
    client.println(SERVER);
    client.println("User-Agent: LED Sectional Client");
    client.println("Connection: close");
    client.println();
    client.flush();
    t = millis(); // start time
    FastLED.clear();

    Serial.print("Getting data");

    while (!client.connected()) {
      if ((millis() - t) >= (READ_TIMEOUT * 1000)) {
        Serial.println("---Timeout---");
        client.stop();
        return false;
      }
      Serial.print(".");
      delay(1000);
    }

    Serial.println();
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
WKHarmon, 2021-07-25:
I think that this may be a hardware issue rather than a software one. It looks like that first LED isn't getting the data signals properly because it is both showing the wrong color and it's on full brightness rather than the brightness level you've specified in your code.

Do you happen to have another LED hanging around? If so, can you try replacing that one? Another thing you may want to try is placing a single LED between the module and that first LED. You don't have a logic level shifter there which usually will work fine, but using a sacrificial LED at the beginning can also help in that situation.

Closed 2021-07-26.

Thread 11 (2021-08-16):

“Live” legend?

mosleyh, 2021-08-16:
Just ordered the kit. Is there a way to dedicate LEDs to create a “live” legend?

WKHarmon, 2021-08-16:
Hola! You can list those LEDs as VFR, MVFR, IFR, LIFR, and WVFR (for windy vfr) to use them as a key--that'll cause those LEDs to stay that color at all times while its operating.

Closed 2021-09-20.

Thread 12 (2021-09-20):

LED #1 is bright purple?

mosleyh, 2021-09-20:
Any idea why LED #1 is bright (brighter than LIFR) purple and can't be nulled off? I thought it might be the string but it does the same on multiple strings.

mrkoopa1, 2021-09-27:
> Any idea why LED #1 is bright (brighter than LIFR) purple and can't be nulled off? I thought it might be the string but it does the same on multiple strings.

I was having the same issue, it appears there is an issue with the ESP8266 package past ver 3.0.0. Go into boards manager and remove the current ESP8266 should be ver 3.0.2 and reinstall selecting 2.7.4. The issue was resolved for me after that.

Cheers.

WKHarmon, 2021-09-27:
Thank you for figuring that out! I was actively troubleshooting and
starting to think I had some sort of hardware design issue.

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
--
Kyle Harmon
***@***.***

mosleyh, 2021-09-27:
Thanks @mrkoopa1, that fixed it!

@WKHarmon did you get the METAR spreadsheet that I sent a few weeks ago?

Closed 2021-09-29.

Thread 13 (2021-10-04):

Power off Battery

sean-smith, 2021-10-04:
Is there an easy way to power off a battery? Was thinking it'd be great to enclose this completely in the frame with a rechargable battery. Unfortunately my knowledge of hardware is a bit limited, it seems like I could just find a cord that outputs 5V USB to the same size adapter, like [this](https://www.amazon.com/StarTech-com-USB2TYPEM-Barrel-Power-Cable/dp/B003MQO96U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)

What do you suggest?

WKHarmon, 2021-10-04:
Yup, the Type M one from your link should work fine. I haven't done any proper benchmarking on how much power everything will draw--the microcontroller itself shouldn't draw much at all, but the LEDs will be nontrivial so I'm not sure how long it'll last. It seems worth a shot to grab a larger USB battery bank.

If you have fewer than about 50 LEDs and are using sane brightness levels, it should also be safe to power the entire thing off of the Micro USB port if you already have a USB-A to Micro USB cable lying around. (If you draw too much current on the Micro USB port it'll trip a fuse that will automatically reset itself after being unplugged for a few hours, so it shouldn't do any permanent damage.)

sean-smith, 2022-12-16:
I tested this out with a normal sized external battery and it lasted only a few days. Wasn't worth the hassle of constantly charging the battery.

Closed 2022-12-16.

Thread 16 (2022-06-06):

Error code on startup

Sharke08, 2022-06-06:
Any ideas on what is causing this?

)⸮NP⸮\ ⸮D)⸮T'⸮⸮Z⸮ ⸮
)S
⸮E ⸮Y⸮P9E⸮% )⸮@ @⸮Y⸮ ⸮NRP JJi⸮A p J⸮T P z⸮E⸮ -⸮T5
SDK:2.2.2-dev(38a443e)/Core:2.7.2-7-g5d3af165=20702007/lwIP:STABLE-2_1_2_RELEASE/glue:1.2-30-g92add50/BearSSL:5c771be
Loop: 0
WiFi connecting..scandone
.scandone
state: 0 -> 2 (b0)
state: 2 -> 3 (0)
state: 3 -> 5 (10)
add 0
aid 7
cnt

connected with BentleyBeagle, channel 1
dhcp client start...
ip:192.168.1.138,mask:255.255.255.0,gw:192.168.1.1
OK!
Getting METARs ...

Starting connection to server...
Fatal exception 28(LoadProhibitedCause):
epc1=0x402098a4, epc2=0x00000000, epc3=0x00000000, excvaddr=0x0d140000, depc=0x00000000

Sharke08, 2022-06-10:
I resolved this issue by moving from esp8266 board manager version 2.7.3 to 2.7.4.  Not sure what was causing the fatal error other than it being a somewhat older version of the board manager.

Closed 2022-06-10.

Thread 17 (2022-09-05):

Updating code to be ESP32 compatible

Tapity04, 2022-09-05:
Hi, WKHarmon, really liked your code, but im struggling to update it to be ESP32 "friendly"

At the moment my changes were:
- Modifying the library from _ESP8266WiFi.h_ to _WiFi.h_
- BearSSL changed to WiFiClient leaving the underneath code as it is
- Debug: true

Right now my worst nightmare is the GET from aviationweather.gov, the query is being sent but the data received is not being decoded. Only the "default" leds are lightning up (VFR, IFR, etc.)

Here's the editted code if there's something weird looking
`#include <WiFi.h>
#include <FastLED.h>
#include <vector>
using namespace std;

#define FASTLED_ESP8266_RAW_PIN_ORDER

#define NUM_AIRPORTS 5 // This is really the number of LEDs
#define WIND_THRESHOLD 30 // Maximum windspeed for green, otherwise the LED turns yellow
#define LOOP_INTERVAL 5000 // ms - interval between brightness updates and lightning strikes
#define DO_LIGHTNING true // Lightning uses more power, but is cool.
#define DO_WINDS true // color LEDs for high winds
#define REQUEST_INTERVAL 900000 // How often we update. In practice LOOP_INTERVAL is added. In ms (15 min is 900000)

#define USE_LIGHT_SENSOR false // Set USE_LIGHT_SENSOR to true if you're using any light sensor.
// Set LIGHT_SENSOR_TSL2561 to true if you're using a TSL2561 digital light sensor.
// Kits shipped after March 1, 2019 have a digital light sensor. Setting this to false assumes an analog light sensor.
#define LIGHT_SENSOR_TSL2561 false

const char ssid[] = "MySsid"; // your network SSID (name)
const char pass[] = "MyVerySecurePassword"; // your network password (use for WPA, or use as key for WEP)

// Define the array of leds
CRGB leds[NUM_AIRPORTS];
#define DATA_PIN    5 // Kits shipped after March 1, 2019 should use 14. Earlier kits us 5.
#define LED_TYPE    WS2811
#define COLOR_ORDER RGB
#define BRIGHTNESS 20 // 20-30 recommended. If using a light sensor, this is the initial brightness on boot.

/* This section only applies if you have an ambient light sensor connected */
#if USE_LIGHT_SENSOR
/* The sketch will automatically scale the light between MIN_BRIGHTNESS and
MAX_BRIGHTNESS on the ambient light values between MIN_LIGHT and MAX_LIGHT
Set MIN_BRIGHTNESS and MAX_BRIGHTNESS to the same value to achieve a simple on/off effect. */
#define MIN_BRIGHTNESS 20 // Recommend values above 4 as colors don't show well below that
#define MAX_BRIGHTNESS 20 // Recommend values between 20 and 30

// Light values are a raw reading for analog and lux for digital
#define MIN_LIGHT 16 // Recommended default is 16 for analog and 2 for lux
#define MAX_LIGHT 30 // Recommended default is 30 to 40 for analog and 20 for lux

#if LIGHT_SENSOR_TSL2561
#include <Adafruit_Sensor.h>
#include <Adafruit_TSL2561_U.h>
#include <Wire.h>
Adafruit_TSL2561_Unified tsl = Adafruit_TSL2561_Unified(TSL2561_ADDR_FLOAT, 12345);
#else
#define LIGHTSENSORPIN A0 // A0 is the only valid pin for an analog light sensor
#endif

#endif
/* ----------------------------------------------------------------------- */

std::vector<unsigned short int> lightningLeds;
std::vector<String> airports({
  "LIFR", // 1 order of LEDs, starting with 1 should be KKIC; use VFR, WVFR, MVFR, IFR, LIFR for key; NULL for no airport
  "IFR", // 2
  "MVFR", // 3
  "WVFR", // 4
  "VFR", // 5
  "SAEZ", // 6
  "SADF", // 7
  "SAAR", // 8
  "SAZM", // 9
  "KCVH", // 10
  "KWVI", // 11
  "KE16", // 12
  "SABE" // 80 I limited the number of airports trying to find if the big quantity of airports affected the GET
});

#define DEBUG true

#define READ_TIMEOUT 15 // Cancel query if no data received (seconds)
#define WIFI_TIMEOUT 60 // in seconds
#define RETRY_TIMEOUT 15000 // in ms

#define SERVER "www.aviationweather.gov"
#define BASE_URI "/adds/dataserver_current/httpparam?dataSource=metars&requestType=retrieve&format=xml&hoursBeforeNow=3&mostRecentForEachStation=true&stationString="

boolean ledStatus = true; // used so leds only indicate connection status on first boot, or after failure
int loops = -1;

int status = WL_IDLE_STATUS;

void setup() {
  //Initialize serial and wait for port to open:
  Serial.begin(74880);
  //pinMode(D1, OUTPUT); //Declare Pin mode
  //while (!Serial) {
  //    ; // wait for serial port to connect. Needed for native USB
  //}

  pinMode(LED_BUILTIN, OUTPUT); // give us control of the onboard LED
  digitalWrite(LED_BUILTIN, LOW);

  #if USE_LIGHT_SENSOR
  #if LIGHT_SENSOR_TSL2561
  Wire.begin(D2, D1);
  if(!tsl.begin()) {
    /* There was a problem detecting the TSL2561 ... check your connections */
    Serial.println("Ooops, no TSL2561 detected ... Check your wiring or I2C ADDR!");
  } else {
    tsl.enableAutoRange(true);
    tsl.setIntegrationTime(TSL2561_INTEGRATIONTIME_13MS);
  }
  #else
  pinMode(LIGHTSENSORPIN, INPUT);
  #endif
  #endif

  // Initialize LEDs
  FastLED.addLeds<LED_TYPE, DATA_PIN, COLOR_ORDER>(leds, NUM_AIRPORTS).setCorrection(TypicalLEDStrip);
  FastLED.setBrightness(BRIGHTNESS);
}

#if USE_LIGHT_SENSOR
void adjustBrightness() {
  unsigned char brightness;
  float reading;

  #if LIGHT_SENSOR_TSL2561
  sensors_event_t event;
  tsl.getEvent(&event);
  reading = event.light;
  #else
  reading = analogRead(LIGHTSENSORPIN);
  #endif

  Serial.print("Light reading: ");
  Serial.print(reading);
  Serial.print(" raw, ");

  if (reading <= MIN_LIGHT) brightness = 0;
  else if (reading >= MAX_LIGHT) brightness = MAX_BRIGHTNESS;
  else {
    // Percentage in lux range * brightness range + min brightness
    float brightness_percent = (reading - MIN_LIGHT) / (MAX_LIGHT - MIN_LIGHT);
    brightness = brightness_percent * (MAX_BRIGHTNESS - MIN_BRIGHTNESS) + MIN_BRIGHTNESS;
  }

  Serial.print(brightness);
  Serial.println(" brightness");
  FastLED.setBrightness(brightness);
  FastLED.show();
}
#endif

void loop() {
  digitalWrite(LED_BUILTIN, LOW); // on if we're awake

  #if USE_LIGHT_SENSOR
  adjustBrightness();
  #endif

  int c;
  loops++;
  Serial.print("Loop: ");
  Serial.println(loops);
  unsigned int loopThreshold = 1;
  if (DO_LIGHTNING || USE_LIGHT_SENSOR) loopThreshold = REQUEST_INTERVAL / LOOP_INTERVAL;

  // Connect to WiFi. We always want a wifi connection for the ESP8266
  if (WiFi.status() != WL_CONNECTED) {
    if (ledStatus) fill_solid(leds, NUM_AIRPORTS, CRGB::Orange); // indicate status with LEDs, but only on first run or error
    FastLED.show();
    WiFi.mode(WIFI_STA);
    WiFi.hostname("LED Sectional " + WiFi.macAddress());
    //wifi_set_sleep_type(LIGHT_SLEEP_T); // use light sleep mode for all delays
    Serial.print("WiFi connecting..");
    WiFi.begin(ssid, pass);
    // Wait up to 1 minute for connection...
    for (c = 0; (c < WIFI_TIMEOUT) && (WiFi.status() != WL_CONNECTED); c++) {
      Serial.write('.');
      delay(1000);
    }
    if (c >= WIFI_TIMEOUT) { // If it didn't connect within WIFI_TIMEOUT
      Serial.println("Failed. Will retry...");
      fill_solid(leds, NUM_AIRPORTS, CRGB::Orange);
      FastLED.show();
      ledStatus = true;
      return;
    }
    Serial.println("OK!");
    if (ledStatus) fill_solid(leds, NUM_AIRPORTS, CRGB::Purple); // indicate status with LEDs
    FastLED.show();
    ledStatus = false;
  }

  // Do some lightning
  if (DO_LIGHTNING && lightningLeds.size() > 0) {
    std::vector<CRGB> lightning(lightningLeds.size());
    for (unsigned short int i = 0; i < lightningLeds.size(); ++i) {
      unsigned short int currentLed = lightningLeds[i];
      lightning[i] = leds[currentLed]; // temporarily store original color
      leds[currentLed] = CRGB::White; // set to white briefly
      Serial.print("Lightning on LED: ");
      Serial.println(currentLed);
    }
    delay(25); // extra delay seems necessary with light sensor
    FastLED.show();
    delay(25);
    for (unsigned short int i = 0; i < lightningLeds.size(); ++i) {
      unsigned short int currentLed = lightningLeds[i];
      leds[currentLed] = lightning[i]; // restore original color
    }
    FastLED.show();
  }

  if (loops >= loopThreshold || loops == 0) {
    loops = 0;
    if (DEBUG) {
      fill_gradient_RGB(leds, NUM_AIRPORTS, CRGB::Red, CRGB::Blue); // Just let us know we're running
      FastLED.show();
    }

    Serial.println("Getting METARs ...");
    if (getMetars()) {
      Serial.println("Refreshing LEDs.");
      FastLED.show();
      if ((DO_LIGHTNING && lightningLeds.size() > 0) || USE_LIGHT_SENSOR) {
        Serial.println("There is lightning or we're using a light sensor, so no long sleep.");
        digitalWrite(LED_BUILTIN, HIGH);
        delay(LOOP_INTERVAL); // pause during the interval
      } else {
        Serial.print("No lightning; Going into sleep for: ");
        Serial.println(REQUEST_INTERVAL);
        digitalWrite(LED_BUILTIN, HIGH);
        delay(REQUEST_INTERVAL);
      }
    } else {
      digitalWrite(LED_BUILTIN, HIGH);
      delay(RETRY_TIMEOUT); // try again if unsuccessful
    }
  } else {
    digitalWrite(LED_BUILTIN, HIGH);
    delay(LOOP_INTERVAL); // pause during the interval
  }
}

bool getMetars(){
  lightningLeds.clear(); // clear out existing lightning LEDs since they're global
  fill_solid(leds, NUM_AIRPORTS, CRGB::Black); // Set everything to black just in case there is no report
  uint32_t t;
  char c;
  boolean readingAirport = false;
  boolean readingCondition = false;
  boolean readingWind = false;
  boolean readingGusts = false;
  boolean readingWxstring = false;

  std::vector<unsigned short int> led;
  String currentAirport = "";
  String currentCondition = "";
  String currentLine = "";
  String currentWind = "";
  String currentGusts = "";
  String currentWxstring = "";
  String airportString = "";
  bool firstAirport = true;
  for (int i = 0; i < NUM_AIRPORTS; i++) {
    if (airports[i] != "NULL" && airports[i] != "VFR" && airports[i] != "MVFR" && airports[i] != "WVFR" && airports[i] != "IFR" && airports[i] != "LIFR") {
      if (firstAirport) {
        firstAirport = false;
        airportString = airports[i];
      } else airportString = airportString + "," + airports[i];
    }
  }

  WiFiClient client;
  Serial.println("\nStarting connection to server...");
  // if you get a connection, report back via serial:
  if (!client.connect(SERVER, 80)) {
    Serial.println("Connection failed!");
    client.stop();
    return false;
  } else {
    Serial.println("Connected ...");
    Serial.print("GET ");
    Serial.print(BASE_URI);
    Serial.print(airportString);
    Serial.println(" HTTP/1.1");
    Serial.print("Host: ");
    Serial.println(SERVER);
    Serial.println("User-Agent: LED Map Client");
    Serial.println("Connection: close");
    Serial.println();
    // Make a HTTP request, and print it to console:
    client.print("GET ");
    client.print(BASE_URI);
    client.print("airportString");
    client.println(" HTTP/1.1");
    client.print("Host: ");
    client.println(SERVER);
    client.println("User-Agent: LED Sectional Client");
    client.println("Connection: close");
    client.println();
    client.flush();
    t = millis(); // start time
    FastLED.clear();

    Serial.print("Getting data");
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
bentmettle, 2022-12-16:
Are you running with the serial monitor?

You should be seeing the stations update with the parsed data-

WiFi connecting.......OK!
Getting METARs ...

Starting connection to server...
Connected ...
GET /adds/dataserver_current/httpparam?dataSource=metars&requestType=retrieve&format=xml&hoursBeforeNow=3&mostRecentForEachStation=true&stationString=KIKV,KARB,KTNU,KDTW HTTP/1.1
Host: www.aviationweather.gov
User-Agent: LED Map Client
Connection: close

Getting data
KTNU: MVFR 16G21kts LED 14 WX:
KIKV: IFR 8G17kts LED 12 WX: -SN
KARB: LIFR 6G0kts LED 13 WX: BR
KDTW: IFR 11G17kts LED 50 WX:

knowing if you are getting that data output in the serial monitor would help you understand if you have a problem parsing the response from the server or something with the calls to update the LED states.

Closed 2025-09-26.

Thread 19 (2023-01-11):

Add time based auto-adjust brightness

jivebiscuit, 2023-01-11:
Hello! Just finished my metar map with your code and it’s working great. In addition to the brightness sensor option - is there a way to add time based brightness levels to the sketch loop?

Even something hard coded like brightness A during these hours then brightness B during these other hours might be useful. I wish I could help and explore the code myself but I’m still coming up to speed on arduino programming. I’m not even sure if the sketch is aware of the time though it could be parsed from the raw metars as they include time.

Thanks and feel free to delete or move if this is not the appropriate place for feature requests.

WKHarmon, 2025-09-26:
Mass closing some old issues that aren't planned.

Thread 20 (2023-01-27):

A more detailed install or readme for newbs

nesincg, 2023-01-27:
My venture to this unknown area of Arduino will be be very apparent and I apologize.

I purchased your kit several months ago and am now getting down to making a map. I've made 6 in the past using pi zeros, but your pre-finished hardware looked great. Now I'm down to having no idea how to install your software. I sort of figured your kit would already have the software pre-installed and I'd just upload an airports file or something. That might be the case, I just don't know.

I downloaded the code and the only thing I can make sense of is led-sectional.ino. Seems like I would config and then upload that, but I can't figure that part out either. I have Arduino IDE and your board connected via USB but I can't upload anything. I says no such file or directory.  It could by my choice of board in IDE as I can't seem to find one that would match your hardware.

I know you don't really supply help, but a beginner readme or install would be awesome. Perhaps I'm missing it. Perhaps you want to reach out via email, I'm cnesin on the Gmail. Thanks a million in advance. Chris

jivebiscuit, 2023-01-27:
You know I'm trying to build a portfolio of technical writing - give me some time and I might be able to hammer something out for you and the project.

jivebiscuit, 2023-01-27:
Which Arduino board are you using specifically?

nesincg, 2023-01-28:
Thanks for getting back to me. I'm using the board from your kit.

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

jivebiscuit, 2023-01-28:
I'm not the author  of the project, just another user, so I'm not familiar with the kit you're referring too.

JazzerAlto, 2023-03-09:
You need the Ardurino IDE.  https://www.arduino.cc/en/software. This will load the ino file and you can load it on to the board after you have configured your wifi and airport list.  Refer to the software section on Kyle's site for more details on what libraries you need to install inside the software to make it compile correctly for the kit.

WKHarmon, 2025-09-26:
Mass closing some old issues.

Closed 2025-09-26.

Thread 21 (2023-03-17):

More of a question than an issue

dandspach, 2023-03-17:
More of a question than an issue.  Suppose one wanted to use a Wemos D1 Mini, instead of the ESP8266.  How difficult would it be to change the code referencing the ESP to allow for use of a Wemos D1?  The Wemos D1 has a 5v output which, is better for driving more leds.

I have been running a METAR map on a Raspberry PI since Covid lockdowns and like the simplicity of this code.  Using this would free up my PI for another project.

Thanks, very cool project.

WKHarmon, 2023-03-17:
Hola! I designed the entire project for a Wemos D1 Mini, so it should work out of the box just fine. (The Wemos uses an ESP8266 as its microcontroller.) But all of the logic pins on the Wemos are 3.3v, not 5v. I’ve found that usually LED strands will accept that 3.3v logic just fine so it may not be necessary to add the level shifting ICs to get it to 5v, but your mileage may vary.

Closed 2025-09-26.

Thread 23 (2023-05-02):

esphome?

kdknigga, 2023-05-02:
Nice. I see that you also implemented WiFiManager, which is something that I've been meaning to do for a while.

_Originally posted by @WKHarmon in https://github.com/WKHarmon/led-sectional/issues/22#issuecomment-1532061796_

New issue to not sidetrack the other...  Really more of a discussion than issue.

Have you seen [ESPHome](https://esphome.io/index.html)?  I wonder if this whole project could be refactored into an ESPHome component or two, and let ESPHome handle WiFi, LEDs, maybe even an html interface for managing airport to LED mapping.  They even have a way to join devices to WiFi easily, [Improv](https://www.improv-wifi.com/).

jcl-rv12is, 2023-05-02:
Go for it!  I'm brand new to microcontrollers, and without too much effort was able to make the changes in my fork.  For something that's less than 500 lines (excluding comments), I'm not personally inclined to do much more.  WiFiManager does a fine job of letting you join a new WiFi network, and eliminates the problem I had with the WiFi library not working well with some routers (unable to get an address via DHCP), which is what drove me to it.

Ahmedk1995, 2023-05-04:
> Go for it! I'm brand new to microcontrollers, and without too much effort was able to make the changes in my fork. For something that's less than 500 lines (excluding comments), I'm not personally inclined to do much more. WiFiManager does a fine job of letting you join a new WiFi network, and eliminates the problem I had with the WiFi library not working well with some routers (unable to get an address via DHCP), which is what drove me to it.

Thank you for including WiFiManager in your fork, I haven't been able to find a way to message you or open an issue so I'll ask here, I noticed that when LEDs blink due to high winds or lightning, it causes the board to auto connect again which causes a bit of a delay, you can see that behaviour in the serial monitor. I was wondering if that's intended behaviour or a bug?

jcl-rv12is, 2023-05-05:
> Thank you for including WiFiManager in your fork, I haven't been able to find a way to message you or open an issue so I'll ask here, I noticed that when LEDs blink due to high winds or lightning, it causes the board to auto connect again which causes a bit of a delay, you can see that behaviour in the serial monitor. I was wondering if that's intended behaviour or a bug?

The "delay" you're seeing is not because of any WiFi activity.  Rather, there is a delay/loop introduced whenever there is a need for LEDs to blink, i.e. whenever lightning/thunderstorms or high winds are found, so that there is time for the blinking activity of the lights.  That delay has always been there.  With the original code, you'll see something like the text below in the output when "lightning", i.e. thunderstorms, are found. It's that same loop being executed with my changes.

There is lightning or we're using a light sensor, so no long sleep.
Loop: 1
Lightning on LED: 0
Loop: 2
Lightning on LED: 0
Loop: 3
Lightning on LED: 0

Ahmedk1995, 2023-05-05:
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

I should have clarified, I understand the delay is there for a reason, what I mean is that everything the "Loop" goes off, WM decides to restart the autoconnect procedure. Looking at my serial monitor this is what I see every 5-10 seconds when high winds/lightning are detected

There is lightning, thunderstorms or high wind, or we're using a light sensor, so no long sleep.
Loop: 1
*WM:
*WM: AutoConnect
*WM: Connecting as wifi client...
*WM: Status:
*WM: 3
*WM: Using last saved values, should be faster
*WM: Connection result:
*WM: 3
*WM: IP Address:
*WM: 192.168.68.124
Connected to local network
High wind on LED: 1
Loop: 2
*WM:
*WM: AutoConnect
*WM: Connecting as wifi client...
*WM: Status:
*WM: 3
*WM: Using last saved values, should be faster
*WM: Connection result:
*WM: 3
*WM: IP Address:
*WM: 192.168.68.124
Connected to local network
High wind on LED: 1
Loop: 3
*WM:
*WM: AutoConnect
*WM: Connecting as wifi client...
*WM: Status:
*WM: 3
*WM: Using last saved values, should be faster
*WM: Connection result:
*WM: 3
*WM: IP Address:
*WM: 192.168.68.124
Connected to local network
High wind on LED: 1
Loop: 4
*WM:
*WM: AutoConnect
*WM: Connecting as wifi client...
*WM: Status:
*WM: 3
*WM: Using last saved values, should be faster

Is this normal behaviour? Should it not stay connected from bootup and only loop to refresh the lights instead of calling the wifi connection every time it loops?

jcl-rv12is, 2023-05-06:
I'm not sure how the output you showed differed from mine...must have made some edits?  It never actually reconnected, rather I would get messages that it was already connected.

Regardless, there was a defect, which has been fixed.  Thanks for the feedback!

Closed 2023-10-17.

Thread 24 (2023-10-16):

API down?

sean-smith, 2023-10-16:
My map stopped displaying anything today after several years of usage. I’m assuming this means either the aviationweather.gov API is down or they’ve changed the API format. I confirmed and the same issue is effecting another map I made for a friend.

Anyone else having this issue?

sean-smith, 2023-10-16:
This looks related: https://github.com/WKHarmon/led-sectional/commit/d2265f399e76dc45e15e23fb35ffab70afa7a45c

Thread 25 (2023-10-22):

New install turns off LEDs when room is dark

jasonfish, 2023-10-22:
My first build was about 4 years ago, has been running fine. I recently pulled all the latest changes due to the URL change, re-inserted all my parameters, and built to the same HUZZAH board. All seems to work the same except the lowest brightness threshold.

In the past, the map brightness would lower to a certain point (50) and just stay there, no matter how dark the room got. Now though, the light reading seems to bounce above/below some unknown boundary, so the whole map constantly turns on and off. It's not rebooting; it's fully colored, then off, then fully colored again. This is easiest to repro by walking past the map, as my shadow can change the ambient light _just_ enough, but it also does this when I'm sitting across the room, which is pretty distracting.

My settings used to be
#define MIN_BRIGHTNESS 50
#define MAX_BRIGHTNESS 255
#define MIN_LIGHT 1
#define MAX_LIGHT 1024

I've tried changing the MIN_LIGHT to 16 as suggested in the sketch, but this seems to make the map turn off in even brighter light (worse). Setting MIN_LIGHT to 0 seems to help, but doesn't solve it.

How can I set the map to _never_ turn completely off, yet retain the auto-brightness functionality?

jasonfish, 2024-03-02:
Any ideas?

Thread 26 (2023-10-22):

Lighting with LED #1

timmyjane, 2023-10-22:
Since we are having to update the API it is probably worth reminding everyone that the ESP8266 board manager has to be on v2.7.4 for the LEDs to work correctly.  After so many years of having my map up and running I had forgotten that it was an issue or perhaps I built my map before it was an issue.
Either way, it took me a while to figure it out until I saw the closed issue tab.  :)

Kyle-  Maybe add a note in the code??

mhawk1134, 2024-01-11:
Hey I've been trying to roll back to v2.7.4 & just cant figure out what I'm doing wrong. I've downloaded the zip for it but IDE wont accept the library.

timmyjane, 2024-01-11:
Delete the library from your PC and then download 2.7.4. Also in the newer web (?)Arduino IDE, you can choose the version. I think that automatically deletes and installs the selected version.

mhawk1134, 2024-01-12:
I deleted the old library in the packages folder (Adruino15), copied in the 2.7.4 and I get:

Platform 'esp8266:esp8266' not found: platform not installed
Compilation error: Platform 'esp8266:esp8266' not found: platform not installed

I made sure to delete the .json URL in the preferences settings under Additional boards manager URLs too.

timmyjane, 2024-01-12:
Sounds like you deleted the esp8266 board from the IDE. Need to add it back.
________________________________
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

mhawk1134, 2024-01-12:
> Sounds like you deleted the esp8266 board from the IDE. Need to add it back.
> […](#)
> ________________________________ From: mhawk1134 ***@***.***> Sent: Thursday, January 11, 2024 7:03:13 PM To: WKHarmon/led-sectional ***@***.***> Cc: timmyjane ***@***.***>; Author ***@***.***> Subject: Re: [WKHarmon/led-sectional] Lighting with LED #1 (Issue #26) I deleted the old library in the packages folder (Adruino15), copied in the 2.7.4 and I get: Platform 'esp8266:esp8266' not found: platform not installed Compilation error: Platform 'esp8266:esp8266' not found: platform not installed I made sure to delete the .json URL in the preferences settings under Additional boards manager URLs too. — Reply to this email directly, view it on GitHub<[#26 (comment)](https://github.com/WKHarmon/led-sectional/issues/26#issuecomment-1888161514)>, or unsubscribe<https://github.com/notifications/unsubscribe-auth/ABNORJCB6C37JYQ3X6IDMODYOB4UDAVCNFSM6AAAAAA6LEZJAOVHI2DSMVQWIX3LMV43OSLTON2WKQ3PNVWWK3TUHMYTQOBYGE3DCNJRGQ>. You are receiving this because you authored the thread.Message ID: ***@***.***>

Yeah I did, I updated my comment for my newest issue lol

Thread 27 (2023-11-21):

FastLED.h breaks if version > 3.4.0 is installed

b-hud, 2023-11-21:
After updating the [aviationweather source](https://github.com/WKHarmon/led-sectional/commit/d2265f399e76dc45e15e23fb35ffab70afa7a45c), I reflashed my code. On reboot, the ESP only lit up the first LED on the string. I sequentially downgraded fastled.h from 3.6.0, to 3.5.0, to 3.4.0. The LEDs worked as intended once 3.4.0 was installed.

nheyland, 2024-02-11:
Just a bump - this was an issue for me as well, thanks for pointing it out 3.4.0,  works well for me now.

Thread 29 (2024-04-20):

cannot get over 54 airports to load.

jbilleaudeaux, 2024-04-20:
Map is up and running fine with 54 airports and less.  When I add more than 55 airports I get an exception code 28 in the stack and it keeps on scrolling over and over infinitely.   LEDS switch amber to magenta and back.    Hoping to locate the issue as I'd like to build a US map.   Thanks so much for the help in advance

Versions are 2.74 esp8266  Board is a ESP8266 ESP-12E CP2102 NodeMCU Lua
fast LED 3.3
Wifi Manager 2.016-rc2 tzapu.

_**Here is the code  some airports randomly added at the end, just to see.   Airport names are incorrect.**_

ERROR CODE COPIED AT THE BOTTOM

#include <ESP8266WiFi.h>
#include <FastLED.h>  // IMPORTANT USE FASTLED V3.4 ONLY
#include <vector>
#include <WiFiManager.h> // https://github.com/tzapu/WiFiManager

using namespace std;

#define FASTLED_ESP8266_RAW_PIN_ORDER

#define NUM_AIRPORTS 57 // This is really the number of LEDs
#define WIND_THRESHOLD 25 // Maximum windspeed for green, otherwise the LED turns yellow
#define LOOP_INTERVAL 5000 // ms - interval between brightness updates and lightning strikes
#define DO_LIGHTNING true // Lightning uses more power, but is cool.
#define DO_WINDS true // color LEDs for high winds
#define REQUEST_INTERVAL 180000 // How often we update. In practice LOOP_INTERVAL is added. In ms (5 min is 300000)

#define USE_LIGHT_SENSOR false // Set USE_LIGHT_SENSOR to true if you're using any light sensor.
// Set LIGHT_SENSOR_TSL2561 to true if you're using a TSL2561 digital light sensor.
// Kits shipped after March 1, 2019 have a digital light sensor. Setting this to false assumes an analog light sensor.
#define LIGHT_SENSOR_TSL2561 false

// WIFI Management for ESP8266
WiFiManager wm;
#define WIFI_TIMEOUT 120 // in seconds
// Parameters for ESP8266 access point
#define ESP_WIFI_SSID "METAR Map"
#define ESP_WIFI_PASSWORD "123456789"

// Define the array of leds
CRGB leds[NUM_AIRPORTS];
#define DATA_PIN    5 // Kits shipped after March 1, 2019 should use 14. Earlier kits us 5.
#define LED_TYPE    WS2812B
#define COLOR_ORDER GRB
#define BRIGHTNESS 20 // 20-30 recommended. If using a light sensor, this is the initial brightness on boot.

/* This section only applies if you have an ambient light sensor connected */
#if USE_LIGHT_SENSOR
/* The sketch will automatically scale the light between MIN_BRIGHTNESS and
MAX_BRIGHTNESS on the ambient light values between MIN_LIGHT and MAX_LIGHT
Set MIN_BRIGHTNESS and MAX_BRIGHTNESS to the same value to achieve a simple on/off effect. */
#define MIN_BRIGHTNESS 20 // Recommend values above 4 as colors don't show well below that
#define MAX_BRIGHTNESS 20 // Recommend values between 20 and 30

// Light values are a raw reading for analog and lux for digital
#define MIN_LIGHT 16 // Recommended default is 16 for analog and 2 for lux
#define MAX_LIGHT 30 // Recommended default is 30 to 40 for analog and 20 for lux

#if LIGHT_SENSOR_TSL2561
#include <Adafruit_Sensor.h>
#include <Adafruit_TSL2561_U.h>
#include <Wire.h>
Adafruit_TSL2561_Unified tsl = Adafruit_TSL2561_Unified(TSL2561_ADDR_FLOAT, 12345);
#else
#define LIGHTSENSORPIN A0 // A0 is the only valid pin for an analog light sensor
#endif

#endif
/* ----------------------------------------------------------------------- */
std::vector<unsigned short int> lightningLeds;
std::vector<String> airports({
  "KNRS", // 1 IMPERIAL BEACH
  "KSDM", // 2 BROWN
  "KNZY", // 3 EL CENTRO
  "KSAN", // 4 IMPERIAL
  "KMYF", // 5 BORREGO
  "KSEE", // 6 RAMONA
  "KRNM", // 7 GILLESPIE
  "KNKX", // 8 NORTH ISLAND
  "KCRQ", // 9 SAN DIEGO
  "KOKB", // 10 MONTGOMERY
  "KNFG", // 11 MIRAMAR
  "KL18", // 12 PALOMAR
  "KF70", // 13 OCEANSIDE
  "KL08", // 14 FALLBROOK
  "KNJK", // 15 FRENCH VALLEY
  "KIPL", // 16  HEMET
  "KTRM", // 17 PALM SPRINGS
  "KPSP", // 18 THERMAL
  "KHMT", // 19 BIG BEAR
  "KRIV", // 20 MARCH
  "KRAL", // 21 SAN BERNARDINO
  "KAJO", // 22 RIVERSIDE
  "KCNO", // 23 JOHN WAYNE
  "KSBD", // 24 CATALINA
  "KONT", // 25 TORRANCE
  "KCCB", // 26 LONG BEACH
  "KPOC", // 27 LOS ALAMITOS NWS
  "KEMT", // 28 FULLERTON
  "KSNA", // 29 CORONA
  "KAVX", // 30 CHINO
  "KTOA", // 31 ONTARIO
  "KLGB", // 32 CABLE
  "KSLI", // 33 BRACKETT
  "KFUL", // 34 EL MONTE
  "KHHR", // 35 HAWTHORNE
  "KLAX", // 36 LOS ANGELES
  "KSMO", // 37 BURBANK
  "KBUR", // 38 WHITEMAN
  "KWHP", // 39 VAN NUYS
  "KVNY", // 40 SANTA MONICA
  "KNTD", // 41 CAMARILLO
  "KCMA", // 42 OXNARD
  "KOXR", // 43 SANTA BARBARA
  "KSBA", // 44 SANDBERG
  "KTSP", // 45 TEHACHAPI
  "KWJF", // 46 FOX FIELD
  "KPMD", // 47 MOJAVE
  "KMHV", // 48 PALMDALE
  "KEDW", // 49 EDWARDS
  "K9L2", // 50 GRAY BUTTE
  "KVCV", // 51 VICTORVILLE
  "KL35", // 52 DAGGETT
  "KDAG",
  "KTNP",
  "KNFG",
  "KSBD",
  "KRDG"

});

#define DEBUG false

#define READ_TIMEOUT 15 // Cancel query if no data received (seconds)
#define RETRY_TIMEOUT 15000 // in ms

#define SERVER "aviationweather.gov"
#define BASE_URI "/cgi-bin/data/dataserver.php?dataSource=metars&requestType=retrieve&format=xml&hoursBeforeNow=3&mostRecentForEachStation=true&stationString="
boolean ledStatus = true; // used so leds only indicate connection status on first boot, or after failure
int loops = -1;

int status = WL_IDLE_STATUS;

void setup() {

  Serial.begin(9600);

  pinMode(LED_BUILTIN, OUTPUT); // give us control of the onboard LED
  digitalWrite(LED_BUILTIN, LOW);

  #if USE_LIGHT_SENSOR
  #if LIGHT_SENSOR_TSL2561
  Wire.begin(D2, D1);
  if(!tsl.begin()) {
    /* There was a problem detecting the TSL2561 ... check your connections */
    Serial.println("Ooops, no TSL2561 detected ... Check your wiring or I2C ADDR!");
  } else {
    tsl.enableAutoRange(true);
    tsl.setIntegrationTime(TSL2561_INTEGRATIONTIME_13MS);
  }
  #else
  pinMode(LIGHTSENSORPIN, INPUT);
  #endif
  #endif

  // Initialize LEDs
  FastLED.addLeds<LED_TYPE, DATA_PIN, COLOR_ORDER>(leds, NUM_AIRPORTS).setCorrection(TypicalLEDStrip);
  FastLED.setBrightness(BRIGHTNESS);
}

#if USE_LIGHT_SENSOR
void adjustBrightness() {
  unsigned char brightness;
  float reading;

  #if LIGHT_SENSOR_TSL2561
  sensors_event_t event;
  tsl.getEvent(&event);
  reading = event.light;
  #else
  reading = analogRead(LIGHTSENSORPIN);
  #endif

  Serial.print("Light reading: ");
  Serial.print(reading);
  Serial.print(" raw, ");

  if (reading <= MIN_LIGHT) brightness = 0;
  else if (reading >= MAX_LIGHT) brightness = MAX_BRIGHTNESS;
  else {
    // Percentage in lux range * brightness range + min brightness
    float brightness_percent = (reading - MIN_LIGHT) / (MAX_LIGHT - MIN_LIGHT);
    brightness = brightness_percent * (MAX_BRIGHTNESS - MIN_BRIGHTNESS) + MIN_BRIGHTNESS;
  }

  Serial.print(brightness);
  Serial.println(" brightness");
  FastLED.setBrightness(brightness);
  FastLED.show();
}
#endif

void loop() {
  digitalWrite(LED_BUILTIN, LOW); // on if we're awake

  #if USE_LIGHT_SENSOR
  adjustBrightness();
  #endif

  int c;
  loops++;
  Serial.print("Loop: ");
  Serial.println(loops);
  unsigned int loopThreshold = 1;
  if (DO_LIGHTNING || USE_LIGHT_SENSOR) loopThreshold = REQUEST_INTERVAL / LOOP_INTERVAL;

  // Connect to WiFi. We always want a wifi connection for the ESP8266
  if (WiFi.status() != WL_CONNECTED) {
    if (ledStatus) fill_solid(leds, NUM_AIRPORTS, CRGB::Orange); // indicate status with LEDs, but only on first run or error
    FastLED.show();
    WiFi.mode(WIFI_STA);
    wm.setConfigPortalTimeout(WIFI_TIMEOUT);
  }
      if(wm.autoConnect(ESP_WIFI_SSID,ESP_WIFI_PASSWORD)){
          Serial.println("Connected to local network");
          if (ledStatus) fill_solid(leds, NUM_AIRPORTS, CRGB::Purple); // indicate status with LEDs
          FastLED.show();
          ledStatus = false;
      }
      else {
         Serial.println("Failed to connect to local network or hit timeout");
          fill_solid(leds, NUM_AIRPORTS, CRGB::Orange);
          FastLED.show();
          ledStatus = true;
          return;
      }  

  // Do some lightning
  if (DO_LIGHTNING && lightningLeds.size() > 0) {
    std::vector<CRGB> lightning(lightningLeds.size());
    for (unsigned short int i = 0; i < lightningLeds.size(); ++i) {
      unsigned short int currentLed = lightningLeds[i];
      lightning[i] = leds[currentLed]; // temporarily store original color
      leds[currentLed] = CRGB::White; // set to white briefly
      Serial.print("Lightning on LED: ");
      Serial.println(currentLed);
    }
    delay(25); // extra delay seems necessary with light sensor
    FastLED.show();
    delay(25);
    for (unsigned short int i = 0; i < lightningLeds.size(); ++i) {
      unsigned short int currentLed = lightningLeds[i];
      leds[currentLed] = lightning[i]; // restore original color
    }
    FastLED.show();
  }

  if (loops >= loopThreshold || loops == 0) {
    loops = 0;
    if (DEBUG) {
      fill_gradient_RGB(leds, NUM_AIRPORTS, CRGB::Red, CRGB::Blue); // Just let us know we're running
      FastLED.show();
    }

    Serial.println("Getting METARs ...");
    if (getMetars()) {
      Serial.println("Refreshing LEDs.");
      FastLED.show();
      if ((DO_LIGHTNING && lightningLeds.size() > 0) || USE_LIGHT_SENSOR) {
        Serial.println("There is lightning or we're using a light sensor, so no long sleep.");
        digitalWrite(LED_BUILTIN, HIGH);
        delay(LOOP_INTERVAL); // pause during the interval
      } else {
        Serial.print("No lightning; Going into sleep for: ");
        Serial.println(REQUEST_INTERVAL);
        digitalWrite(LED_BUILTIN, HIGH);
        delay(REQUEST_INTERVAL);
      }
    } else {
      digitalWrite(LED_BUILTIN, HIGH);
      delay(RETRY_TIMEOUT); // try again if unsuccessful
    }
  } else {
    digitalWrite(LED_BUILTIN, HIGH);
    delay(LOOP_INTERVAL); // pause during the interval
  }
}

bool getMetars(){
  lightningLeds.clear(); // clear out existing lightning LEDs since they're global
  fill_solid(leds, NUM_AIRPORTS, CRGB::Black); // Set everything to black just in case there is no report
  uint32_t t;
  char c;
  boolean readingAirport = false;
  boolean readingCondition = false;
  boolean readingWind = false;
  boolean readingGusts = false;
  boolean readingWxstring = false;

  std::vector<unsigned short int> led;
  String currentAirport = "";
  String currentCondition = "";
  String currentLine = "";
  String currentWind = "";
  String currentGusts = "";
  String currentWxstring = "";
  String airportString = "";
  bool firstAirport = true;
  for (int i = 0; i < NUM_AIRPORTS; i++) {
    if (airports[i] != "NULL" && airports[i] != "VFR" && airports[i] != "MVFR" && airports[i] != "WVFR" && airports[i] != "IFR" && airports[i] != "LIFR") {
      if (firstAirport) {
        firstAirport = false;
        airportString = airports[i];
      } else airportString = airportString + "," + airports[i];
    }
  }
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
jbilleaudeaux, 2024-04-23:
ended up re-installing ESP8266 libraries and put in 2.74 with 58 LEDS and its working properly now.  Also put 1st light as "NULL" .  Seems to have fixed it.

Closed 2024-04-23.

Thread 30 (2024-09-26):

Last airport ignored

ayryq, 2024-09-26:
I'm using the jcl-rv12is fork and currently have reverted to the led_sectional.ino file as published, except I changed pin number to 14.
I'm not seeing the LED updated for the final airport (K11R)
It does appear in the url string:
```
Starting connection to server...
Connected ...
GET /api/data/metar?format=xml&hoursBeforeNow=3&mostRecentForEachStation=true&ids=KGLS,KT41,KEFD,KHOU,KLVJ,KAXH,KSGR,KLBX,KBYY,KARM,KELA,KTME,KDWH,KIAH,KT78,K6R3,KCXO,KUTS,KCFD,KCLL,K60R,K11R HTTP/1.1
Host: aviationweather.gov
User-Agent: LED Map Client
Connection: close
```
But does not appear in the results list
```
[...]
KCLL: VFR 8G20kts LED 22 WX: KCLL 261653Z 04008G20KT 10SM CLR 29/16 A2992 RMK AO2 SLP127 T02890156
... found very high winds or gusts!
K60R:  0G0kts LED 23 WX: K60R 261735Z AUTO 35011KT 8SM SCT050 29/17 A2987 RMK AO2 SLP031 T02940171 $
Refreshing LEDs.
```

I came at this issue from using my own airports, and a set of 50, and the last one was never included—but I'm seeing the same issue with the pre-configured set.

I'm (currently) running FastLED 3.3.3 and esp8266 3.1.2.

ayryq, 2024-09-26:
As a workaround it's simple to add a dummy airport to the end and increase NUM_AIRPORTS by one. In addition to the dummy airport I'm adding at the beginning since my first LED doesn't behave.

ayryq, 2024-09-26:
Also, and this might require some more testing, I'm seeing weird results from the last displayed airport (i.e. the second-to-last programmed airport, since I added a dummy at the very end).
'''
CYTZ:  0G0kts LED 49 WX: CYTZ 262000Z AUTO 20009KT 9SM CLR 22/16 A3001 RMK SLP162 DENSITY ALT 1100FT
'''
There's wind data, 20009kt, so why is it reporting 0G0kts, and no flight category?

Closed 2025-09-26.

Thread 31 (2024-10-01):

Can I repeat airports?

cmogensen13, 2024-10-01:
I built a 200 LED map using this code which is amazing, thank you!

Now I want to build a taxiway lamp with clear glass, but using only 1 airport. I bought a light ring with 24 LEDs, but I noticed the code doesn't let you repeat airports - it only appears on one LED if you repeat. Does anyone know of an easy way around this in the code?

Roverguyjoe, 2025-01-04:
Did you come up with a solution for this?

cmogensen13, 2025-01-04:
Not yet, no.

Roverguyjoe, 2025-01-05:
Try this..

#include <ESP8266WiFi.h>
#include <WiFiClientSecure.h>
#include <ESP8266HTTPClient.h>
#include <Adafruit_NeoPixel.h>

// Define your Wi-Fi credentials
const char* ssid = "yourssid";
const char* password = "wifipass";

// Define the aviationweather.gov API details
#define SERVER "aviationweather.gov"
#define BASE_URI "/cgi-bin/data/dataserver.php?dataSource=metars&requestType=retrieve&format=xml&hoursBeforeNow=3&mostRecentForEachStation=true&stationString="
const char* airport_code = "KPOE";  // The airport code you want the METAR data for

// LED setup
#define LED_PIN D1  // Define the pin connected to the WS2811 data pin
#define NUM_LEDS 1  // Change to number of leds
Adafruit_NeoPixel strip(NUM_LEDS, LED_PIN, NEO_GRB + NEO_KHZ800);  // Use GRB color order

void setup() {
  Serial.begin(9600);  // Set baud rate to 9600
  strip.begin();
  strip.show();  // Initialize all pixels to 'off'

  WiFi.begin(ssid, password);
  Serial.print("Connecting to Wi-Fi...");

  while (WiFi.status() != WL_CONNECTED) {
    flashTeal();  // Flash teal while waiting for Wi-Fi connection
    delay(500);
    Serial.print(".");
  }
  Serial.println("\nConnected to Wi-Fi");
  Serial.println("Wi-Fi signal strength (RSSI): " + String(WiFi.RSSI()) + " dBm");

  // Test internet connectivity
  testInternetConnectivity();
}

void loop() {
  flashTeal();  // Flash teal while fetching data
  fetchAndDisplayMETAR();
  delay(600000);  // Update every 10 minutes
}

void flashTeal() {
  setLEDColor(0, 128, 128);  // Corrected Teal color (GRB format)
  delay(500);
  setLEDColor(0, 0, 0);  // Turn off
  delay(500);
}

void fetchAndDisplayMETAR() {
  if (WiFi.status() == WL_CONNECTED) {
    WiFiClientSecure client;
    client.setInsecure();  // Disable SSL verification temporarily
    HTTPClient http;

    // Ensure using https:// to connect securely
    String url = "https://" + String(SERVER) + BASE_URI + airport_code;  // Construct the full URL with HTTPS

    Serial.println("Fetching METAR data from URL: " + url);

    http.begin(client, url);  // Use the updated method with WiFiClientSecure
    http.setTimeout(30000);  // Set timeout to 30 seconds

    int httpCode = http.GET();
    Serial.println("HTTP Response Code: " + String(httpCode));

    if (httpCode == 200) {
      String payload = http.getString();
      Serial.println("METAR Data: " + payload);  // Print the raw METAR data
      parseAndSetColor(payload);
    } else if (httpCode == 307) {
      Serial.println("Redirected to: " + http.getLocation());  // Print redirected URL
      fetchAndDisplayMETAR();  // Retry the request
    } else {
      Serial.println("Failed to fetch METAR data. HTTP Error: " + String(httpCode));
    }
    http.end();
  } else {
    Serial.println("Wi-Fi not connected.");
  }
}

void parseAndSetColor(String payload) {
  if (payload.indexOf("<flight_category>VFR</flight_category>") > -1) {
    setLEDColor(0, 255, 0);  // Green for VFR (GRB format)
  } else if (payload.indexOf("<flight_category>MVFR</flight_category>") > -1) {
    setLEDColor(0, 0, 255);  // Blue for MVFR (GRB format)
  } else if (payload.indexOf("<flight_category>IFR</flight_category>") > -1) {
    setLEDColor(255, 0, 0);  // Red for IFR (GRB format)
  } else if (payload.indexOf("<flight_category>LIFR</flight_category>") > -1) {
    setLEDColor(255, 0, 255);  // Magenta for LIFR (GRB format)
  }
}

void setLEDColor(int red, int green, int blue) {
  strip.setPixelColor(0, strip.Color(green, red, blue));  // Correct color order (GRB)
  strip.show();
}

void testInternetConnectivity() {
  WiFiClientSecure client;
  HTTPClient testHttp;
  testHttp.begin(client, "https://www.google.com");  // Use HTTPS here for testing
  int testHttpCode = testHttp.GET();
  Serial.println("Google Test HTTP Response Code: " + String(testHttpCode));
  testHttp.end();
}

Roverguyjoe, 2025-01-05:
Try this..
`#include <ESP8266WiFi.h>
#include <WiFiClientSecure.h>
#include <ESP8266HTTPClient.h>
#include <Adafruit_NeoPixel.h>

// Define your Wi-Fi credentials
const char* ssid = "yourssid";
const char* password = "wifipass";

// Define the aviationweather.gov API details
#define SERVER "aviationweather.gov"
#define BASE_URI "/cgi-bin/data/dataserver.php?dataSource=metars&requestType=retrieve&format=xml&hoursBeforeNow=3&mostRecentForEachStation=true&stationString="
const char* airport_code = "KPOE";  // The airport code you want the METAR data for

// LED setup
#define LED_PIN D1  // Define the pin connected I was using ws2811 cob led that was GRB you might need to adjust
#define NUM_LEDS 1  // Number of leds
Adafruit_NeoPixel strip(NUM_LEDS, LED_PIN, NEO_GRB + NEO_KHZ800);  // Use GRB color order

void setup() {
  Serial.begin(9600);  // Set baud rate to 9600
  strip.begin();
  strip.show();  // Initialize all pixels to 'off'

  WiFi.begin(ssid, password);
  Serial.print("Connecting to Wi-Fi...");

  while (WiFi.status() != WL_CONNECTED) {
    flashTeal();  // Flash teal while waiting for Wi-Fi connection
    delay(500);
    Serial.print(".");
  }
  Serial.println("\nConnected to Wi-Fi");
  Serial.println("Wi-Fi signal strength (RSSI): " + String(WiFi.RSSI()) + " dBm");

  // Test internet connectivity
  testInternetConnectivity();
}

void loop() {
  flashTeal();  // Flash teal while fetching data
  fetchAndDisplayMETAR();
  delay(600000);  // Update every 10 minutes
}

void flashTeal() {
  setLEDColor(0, 128, 128);  // Corrected Teal color (GRB format)
  delay(500);
  setLEDColor(0, 0, 0);  // Turn off
  delay(500);
}

void fetchAndDisplayMETAR() {
  if (WiFi.status() == WL_CONNECTED) {
    WiFiClientSecure client;
    client.setInsecure();  // Disable SSL verification temporarily
    HTTPClient http;

    // Ensure using https:// to connect securely
    String url = "https://" + String(SERVER) + BASE_URI + airport_code;  // Construct the full URL with HTTPS

    Serial.println("Fetching METAR data from URL: " + url);

    http.begin(client, url);  // Use the updated method with WiFiClientSecure
    http.setTimeout(30000);  // Set timeout to 30 seconds

    int httpCode = http.GET();
    Serial.println("HTTP Response Code: " + String(httpCode));

    if (httpCode == 200) {
      String payload = http.getString();
      Serial.println("METAR Data: " + payload);  // Print the raw METAR data
      parseAndSetColor(payload);
    } else if (httpCode == 307) {
      Serial.println("Redirected to: " + http.getLocation());  // Print redirected URL
      fetchAndDisplayMETAR();  // Retry the request
    } else {
      Serial.println("Failed to fetch METAR data. HTTP Error: " + String(httpCode));
    }
    http.end();
  } else {
    Serial.println("Wi-Fi not connected.");
  }
}

void parseAndSetColor(String payload) {
  if (payload.indexOf("<flight_category>VFR</flight_category>") > -1) {
    setLEDColor(0, 255, 0);  // Green for VFR (GRB format)
  } else if (payload.indexOf("<flight_category>MVFR</flight_category>") > -1) {
    setLEDColor(0, 0, 255);  // Blue for MVFR (GRB format)
  } else if (payload.indexOf("<flight_category>IFR</flight_category>") > -1) {
    setLEDColor(255, 0, 0);  // Red for IFR (GRB format)
  } else if (payload.indexOf("<flight_category>LIFR</flight_category>") > -1) {
    setLEDColor(255, 0, 255);  // Magenta for LIFR (GRB format)
  }
}

void setLEDColor(int red, int green, int blue) {
  strip.setPixelColor(0, strip.Color(green, red, blue));  // Correct color order (GRB)
  strip.show();
}

void testInternetConnectivity() {
  WiFiClientSecure client;
  HTTPClient testHttp;
  testHttp.begin(client, "https://www.google.com");  // Use HTTPS here for testing
  int testHttpCode = testHttp.GET();
  Serial.println("Google Test HTTP Response Code: " + String(testHttpCode));
  testHttp.end();
}
`

cmogensen13, 2025-01-05:
Thank you @Roverguyjoe - that works, but only lights one LED on the ring of 24 I have. I changed the NUM_LEDS to a larger number but it has no effect. Any ideas?

Closed 2025-09-26.

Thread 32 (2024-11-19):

Help with only yellow LEDs on boot up

mobileandmonitoring, 2024-11-19:
Hello,

I have purchased a few of Kyle's boards and programmed them successfully. For some reason this time around after programming it turns on and all I get is yellow LEDs. Every LED is solid yellow indefinitely.

I have ESP8266 Core 2.7.4, FastLED 3.0.0 (also tried 3.4.0, 3.6.0). I have tried different brand new LEDs, double checked Wi-Fi info. Would love any diagnosis tips you have.

mobileandmonitoring, 2024-11-19:
`#include <ESP8266WiFi.h>
#include <FastLED.h>
#include <vector>
using namespace std;

#define FASTLED_ESP8266_RAW_PIN_ORDER

#define NUM_AIRPORTS 121 // This is really the number of LEDs
#define WIND_THRESHOLD 25 // Maximum windspeed for green, otherwise the LED turns yellow
#define LOOP_INTERVAL 5000 // ms - interval between brightness updates and lightning strikes
#define DO_LIGHTNING true // Lightning uses more power, but is cool.
#define DO_WINDS true // color LEDs for high winds
#define REQUEST_INTERVAL 900000 // How often we update. In practice LOOP_INTERVAL is added. In ms (15 min is 900000)

#define USE_LIGHT_SENSOR false // Set USE_LIGHT_SENSOR to true if you're using any light sensor.
// Set LIGHT_SENSOR_TSL2561 to true if you're using a TSL2561 digital light sensor.
// Kits shipped after March 1, 2019 have a digital light sensor. Setting this to false assumes an analog light sensor.
#define LIGHT_SENSOR_TSL2561 false

const char ssid[] = "Tacobear"; // your network SSID (name)
const char pass[] = "brightquail529"; // your network password (use for WPA, or use as key for WEP)

// Define the array of leds
CRGB leds[NUM_AIRPORTS];
#define DATA_PIN    14 // Kits shipped after March 1, 2019 should use 14. Earlier kits us 5.
#define LED_TYPE    WS2811
#define COLOR_ORDER RGB
#define BRIGHTNESS 20 // 20-30 recommended. If using a light sensor, this is the initial brightness on boot.

/* This section only applies if you have an ambient light sensor connected */
#if USE_LIGHT_SENSOR
/* The sketch will automatically scale the light between MIN_BRIGHTNESS and
MAX_BRIGHTNESS on the ambient light values between MIN_LIGHT and MAX_LIGHT
Set MIN_BRIGHTNESS and MAX_BRIGHTNESS to the same value to achieve a simple on/off effect. */
#define MIN_BRIGHTNESS 20 // Recommend values above 4 as colors don't show well below that
#define MAX_BRIGHTNESS 20 // Recommend values between 20 and 30

// Light values are a raw reading for analog and lux for digital
#define MIN_LIGHT 16 // Recommended default is 16 for analog and 2 for lux
#define MAX_LIGHT 30 // Recommended default is 30 to 40 for analog and 20 for lux

#if LIGHT_SENSOR_TSL2561
#include <Adafruit_Sensor.h>
#include <Adafruit_TSL2561_U.h>
#include <Wire.h>
Adafruit_TSL2561_Unified tsl = Adafruit_TSL2561_Unified(TSL2561_ADDR_FLOAT, 12345);
#else
#define LIGHTSENSORPIN A0 // A0 is the only valid pin for an analog light sensor
#endif

#endif
/* ----------------------------------------------------------------------- */

std::vector<unsigned short int> lightningLeds;
std::vector<String> airports({
  "VFR", // 1
  "MVFR", // 2
  "IFR", // 3
  "LIFR", // 4
  "WVFR", // 5
  "NULL", // 6
  "PASN", // 7
  "PAAK", // 8
  "PADU", // 9
  "PAUT", // 10
  "PAKF", // 11
  "PACD", // 12
  "PAVC", // 13
  "PASD", // 14
  "PAOU", // 15
  "PAPH", // 16
  "PAII", // 17
  "PAKN", // 18
  "PADQ", // 19
  "PASO", // 20
  "PAHO", // 21
  "PAEN", // 22
  "PAWD", // 23
  "PATO", // 24
  "PALH", // 25
  "PABV", // 26
  "PAAQ", // 27
  "PAWS", // 28
  "PATK", // 29
  "PAGK", // 30
  "PAVD", // 31
  "PACV", // 32
  "PAMD", // 33
  "PAYA", // 34
  "CYDB", // 35
  "PAOR", // 36
  "CYDA", // 37
  "PAEG", // 38
  "PABI", // 39
  "PAFA", // 40
  "PANN", // 41
  "PAIN", // 42
  "PAMH", // 43
  "PATA", // 44
  "PAIM", // 45
  "PABT", // 46
  "PFYU", // 47
  "PAKP", // 48
  "PAFM", // 49
  "PAHL", // 50
  "PARY", // 51
  "PAGA", // 52
  "PAKV", // 53
  "PAMC", // 54
  "PANV", // 55
  "PAHC", // 56
  "PANI", // 57
  "PASV", // 58
  "PAIL", // 59
  "PAIG", // 60
  "PAJZ", // 61
  "PAMB", // 62
  "PAEH", // 63
  "PABE", // 64
  "PAKI", // 65
  "PAOO", // 66
  "PASM", // 67
  "PAMK", // 68
  "PAUN", // 69
  "PAGL", // 70
  "PAOM", // 71
  "PAIW", // 72
  "PASH", // 73
  "PADE", // 74
  "PABL", // 75
  "PASK", // 76
  "PAOT", // 77
  "PAVL", // 78
  "PAPO", // 79
  "PALU", // 80
  "PPIZ", // 81
  "PATQ", // 82
  "PABR", // 83
  "PAQT", // 84
  "PASC", // 85
  "PABA", // 86
  "CYOC", // 87
  "CYZP", // 88
  "PAKW", // 89
  "PAWG", // 90
  "PAKT", // 91
  "CYPR", // 92
  "CYZT", // 93
  "CYAZ", // 94
  "KUIL", // 95
  "KCLM", // 96
  "CYYJ", // 97
  "KFHR", // 98
  "KBLI", // 99
  "KBVS", // 100
  "KPAE", // 101
  "KSEA", // 102
  "KTCM", // 103
  "KOLM", // 104
  "KSHN", // 105
  "KHQM", // 106
  "CYXY", // 107
  "PAGY", // 108
  "PAGS", // 109
  "PAJN", // 110
  "PAGN", // 111
  "PASI", // 112
  "PAFE", // 113
  "PAWG", // 114
  "PAKW", // 115
  "PAKT", // 116
  "CYPR", // 117
  "CYZP", // 118
  "PAAK", // 119
  "PADK", // 120
  "PASY", // 121
});

#define DEBUG false

#define READ_TIMEOUT 15 // Cancel query if no data received (seconds)
#define WIFI_TIMEOUT 60 // in seconds
#define RETRY_TIMEOUT 15000 // in ms

#define SERVER "aviationweather.gov"
#define BASE_URI "/cgi-bin/data/dataserver.php?dataSource=metars&requestType=retrieve&format=xml&hoursBeforeNow=3&mostRecentForEachStation=true&stationString="

boolean ledStatus = true; // used so leds only indicate connection status on first boot, or after failure
int loops = -1;

int status = WL_IDLE_STATUS;

void setup() {
  //Initialize serial and wait for port to open:
  Serial.begin(74880);
  //pinMode(D1, OUTPUT); //Declare Pin mode
  //while (!Serial) {
  //    ; // wait for serial port to connect. Needed for native USB
  //}

  pinMode(LED_BUILTIN, OUTPUT); // give us control of the onboard LED
  digitalWrite(LED_BUILTIN, LOW);

  #if USE_LIGHT_SENSOR
  #if LIGHT_SENSOR_TSL2561
  Wire.begin(D2, D1);
  if(!tsl.begin()) {
    /* There was a problem detecting the TSL2561 ... check your connections */
    Serial.println("Ooops, no TSL2561 detected ... Check your wiring or I2C ADDR!");
  } else {
    tsl.enableAutoRange(true);
    tsl.setIntegrationTime(TSL2561_INTEGRATIONTIME_13MS);
  }
  #else
  pinMode(LIGHTSENSORPIN, INPUT);
  #endif
  #endif

  // Initialize LEDs
  FastLED.addLeds<LED_TYPE, DATA_PIN, COLOR_ORDER>(leds, NUM_AIRPORTS).setCorrection(TypicalLEDStrip);
  FastLED.setBrightness(BRIGHTNESS);
}

#if USE_LIGHT_SENSOR
void adjustBrightness() {
  unsigned char brightness;
  float reading;

  #if LIGHT_SENSOR_TSL2561
  sensors_event_t event;
  tsl.getEvent(&event);
  reading = event.light;
  #else
  reading = analogRead(LIGHTSENSORPIN);
  #endif

  Serial.print("Light reading: ");
  Serial.print(reading);
  Serial.print(" raw, ");

  if (reading <= MIN_LIGHT) brightness = 0;
  else if (reading >= MAX_LIGHT) brightness = MAX_BRIGHTNESS;
  else {
    // Percentage in lux range * brightness range + min brightness
    float brightness_percent = (reading - MIN_LIGHT) / (MAX_LIGHT - MIN_LIGHT);
    brightness = brightness_percent * (MAX_BRIGHTNESS - MIN_BRIGHTNESS) + MIN_BRIGHTNESS;
  }

  Serial.print(brightness);
  Serial.println(" brightness");
  FastLED.setBrightness(brightness);
  FastLED.show();
}
#endif

void loop() {
  digitalWrite(LED_BUILTIN, LOW); // on if we're awake

  #if USE_LIGHT_SENSOR
  adjustBrightness();
  #endif

  int c;
  loops++;
  Serial.print("Loop: ");
  Serial.println(loops);
  unsigned int loopThreshold = 1;
  if (DO_LIGHTNING || USE_LIGHT_SENSOR) loopThreshold = REQUEST_INTERVAL / LOOP_INTERVAL;

  // Connect to WiFi. We always want a wifi connection for the ESP8266
  if (WiFi.status() != WL_CONNECTED) {
    if (ledStatus) fill_solid(leds, NUM_AIRPORTS, CRGB::Orange); // indicate status with LEDs, but only on first run or error
    FastLED.show();
    WiFi.mode(WIFI_STA);
    WiFi.hostname("LED Sectional " + WiFi.macAddress());
    //wifi_set_sleep_type(LIGHT_SLEEP_T); // use light sleep mode for all delays
    Serial.print("WiFi connecting..");
    WiFi.begin(ssid, pass);
    // Wait up to 1 minute for connection...
    for (c = 0; (c < WIFI_TIMEOUT) && (WiFi.status() != WL_CONNECTED); c++) {
      Serial.write('.');
      delay(1000);
    }
    if (c >= WIFI_TIMEOUT) { // If it didn't connect within WIFI_TIMEOUT
      Serial.println("Failed. Will retry...");
      fill_solid(leds, NUM_AIRPORTS, CRGB::Orange);
      FastLED.show();
      ledStatus = true;
      return;
    }
    Serial.println("OK!");
    if (ledStatus) fill_solid(leds, NUM_AIRPORTS, CRGB::Purple); // indicate status with LEDs
    FastLED.show();
    ledStatus = false;
  }

  // Do some lightning
  if (DO_LIGHTNING && lightningLeds.size() > 0) {
    std::vector<CRGB> lightning(lightningLeds.size());
    for (unsigned short int i = 0; i < lightningLeds.size(); ++i) {
      unsigned short int currentLed = lightningLeds[i];
      lightning[i] = leds[currentLed]; // temporarily store original color
      leds[currentLed] = CRGB::White; // set to white briefly
      Serial.print("Lightning on LED: ");
      Serial.println(currentLed);
    }
    delay(25); // extra delay seems necessary with light sensor
    FastLED.show();
    delay(25);
    for (unsigned short int i = 0; i < lightningLeds.size(); ++i) {
      unsigned short int currentLed = lightningLeds[i];
      leds[currentLed] = lightning[i]; // restore original color
    }
    FastLED.show();
  }

  if (loops >= loopThreshold || loops == 0) {
    loops = 0;
    if (DEBUG) {
      fill_gradient_RGB(leds, NUM_AIRPORTS, CRGB::Red, CRGB::Blue); // Just let us know we're running
      FastLED.show();
    }

    Serial.println("Getting METARs ...");
    if (getMetars()) {
      Serial.println("Refreshing LEDs.");
      FastLED.show();
      if ((DO_LIGHTNING && lightningLeds.size() > 0) || USE_LIGHT_SENSOR) {
        Serial.println("There is lightning or we're using a light sensor, so no long sleep.");
        digitalWrite(LED_BUILTIN, HIGH);
        delay(LOOP_INTERVAL); // pause during the interval
      } else {
        Serial.print("No lightning; Going into sleep for: ");
        Serial.println(REQUEST_INTERVAL);
        digitalWrite(LED_BUILTIN, HIGH);
        delay(REQUEST_INTERVAL);
      }
    } else {
      digitalWrite(LED_BUILTIN, HIGH);
      delay(RETRY_TIMEOUT); // try again if unsuccessful
    }
  } else {
    digitalWrite(LED_BUILTIN, HIGH);
    delay(LOOP_INTERVAL); // pause during the interval
  }
}

bool getMetars(){
  lightningLeds.clear(); // clear out existing lightning LEDs since they're global
  fill_solid(leds, NUM_AIRPORTS, CRGB::Black); // Set everything to black just in case there is no report
  uint32_t t;
  char c;
  boolean readingAirport = false;
  boolean readingCondition = false;
  boolean readingWind = false;
  boolean readingGusts = false;
  boolean readingWxstring = false;
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
JohnR727, 2025-01-28:
Have you been able to resolve this issue? I'm having the same issue. I moved and haven't had my map on since February 2024.  I updated the website to the new "aviationweather.com" and uri info and it worked fine prior to the move.

I am running 2.7.4 on the esp8266 and 3.4 for FastLED.  I've tried downgrading FastLED to 3.3.3 & 3.3.0 with no luck.

I also got a new modem from AT&T and updated the user name and password. Not sure if I'm not connecting right? I've double checked my username and password, still stuck on yellow.

mobileandmonitoring, 2025-01-28:
Yes I did resolve it. Drove me nuts. I didn’t realize I was connecting to a
5ghz WiFi connection. After connecting to the 2.4ghz WiFi network ssid it
worked. I’d double check. Sometimes they share the same ssid. You can
usually split them apart with unique names.

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

mobileandmonitoring, 2025-01-28:
Awesome to hear that worked for you. Glad to help!

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

Closed 2025-09-26.

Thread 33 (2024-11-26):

WS2811 Led "0"

LLOYDSCHRISTMASLIGHTS, 2024-11-26:
All of my 2811 strings have this new problem. The first Led "0" lights up red and will not change color. They all were working correctly before I attempted to update the sketches that ran them. The sketch works fine with WS2812B Leds.

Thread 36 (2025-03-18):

Are there any compatibility issues with Arduino IDE 2.3.4?

SumOfAMansLife, 2025-03-18:
I just finished my second LED Sectional build since building my first in 2023 .  The original laptop that I used to upload my sketch to the Arduino board used Arduino IDE 2.0.3. For this second build I downloaded Arduino IDE 2.3.4 to a newer laptop I use at work (because that is where this new LED chart will be placed for all to see). Every time I try to upload the program sketch to the board the compiler would never complete. I am no software engineer by any stretch of the imagination. Are there compatibility issues with 2.3.4? I used the proper esp8266 library (whatever that means), board manager 2.7.4. In short I did all of the proper things here, https://gist.github.com/sean-smith/c9d55b32778464f26395443ac26277c8. FastLED 3.4.0 as well.

I went ahead and uploaded the sketch on my old laptop with IDE 2.0.3. The LED chart works great!

Below are the results of the last incomplete compiler result.  I have also added the two answers Grok gave me, which did not help me at all:

In file included from C:\Users\Matthew Merrell\AppData\Local\Temp.arduinoIDE-unsaved2025213-53280-i0z643.5djn\sketch_mar13b\sketch_mar13b.ino:2:0:
C:\Users\Matthew Merrell\AppData\Local\Arduino15\packages\esp8266\hardware\esp8266\2.7.4\libraries\ESP8266WiFi\src/ESP8266WiFi.h: In function 'void setup()':
C:\Users\Matthew Merrell\AppData\Local\Arduino15\packages\esp8266\hardware\esp8266\2.7.4\libraries\ESP8266WiFi\src/ESP8266WiFi.h:27:8: error: expected unqualified-id before string constant
 extern "C" {
        ^
In file included from C:\Users\Matthew Merrell\AppData\Local\Arduino15\packages\esp8266\hardware\esp8266\2.7.4\libraries\ESP8266WiFi\src/WiFiClientSecure.h:41:0,
                 from C:\Users\Matthew Merrell\AppData\Local\Arduino15\packages\esp8266\hardware\esp8266\2.7.4\libraries\ESP8266WiFi\src/WiFiServerSecure.h:20,
                 from C:\Users\Matthew Merrell\AppData\Local\Arduino15\packages\esp8266\hardware\esp8266\2.7.4\libraries\ESP8266WiFi\src/ESP8266WiFi.h:41,
                 from C:\Users\Matthew Merrell\AppData\Local\Temp.arduinoIDE-unsaved2025213-53280-i0z643.5djn\sketch_mar13b\sketch_mar13b.ino:2:
C:\Users\Matthew Merrell\AppData\Local\Arduino15\packages\esp8266\hardware\esp8266\2.7.4\libraries\ESP8266WiFi\src/WiFiClientSecureBearSSL.h:150:28: error: expected '}' before end of line
 #pragma GCC diagnostic push
                            ^
C:\Users\Matthew Merrell\AppData\Local\Arduino15\packages\esp8266\hardware\esp8266\2.7.4\libraries\ESP8266WiFi\src/WiFiClientSecureBearSSL.h: At global scope:
C:\Users\Matthew Merrell\AppData\Local\Arduino15\packages\esp8266\hardware\esp8266\2.7.4\libraries\ESP8266WiFi\src/WiFiClientSecureBearSSL.h:150:28: error: expected declaration before end of lineexit status 1Compilation error: exit status

Groks answer 1:

The error messages you’ve provided point to a compilation failure when trying to compile a sketch for the ESP8266 using Arduino IDE. However, the errors are unusual because they appear to originate from within the ESP8266WiFi library files (e.g., ESP8266WiFi.h, WiFiClientSecureBearSSL.h), which are part of the ESP8266 core, rather than directly from your sketch (sketch_mar13b.ino). This suggests either a corruption in the library files, a mismatch in versions, or a syntax error in your sketch that’s confusing the compiler and causing it to misinterpret the library headers.
Let’s break it down and fix it step-by-step.
Error Analysis
First Error:
C:\Users\Matthew Merrell\AppData\Local\Arduino15\packages\esp8266\hardware\esp8266\2.7.4\libraries\ESP8266WiFi\src/ESP8266WiFi.h:27:8: error: expected unqualified-id before string constant
 extern "C" {
        ^
Location: Line 27 of ESP8266WiFi.h, which is a core library file.
Problem: The compiler expected an identifier (e.g., a variable or function name) but found the string "C" after extern. This is part of a standard C++ linkage directive (extern "C") used to interface with C code, and it’s not something that should fail unless the file is corrupted or the preprocessor is misinterpreting your code.
Second Error:
C:\Users\Matthew Merrell\AppData\Local\Arduino15\packages\esp8266\hardware\esp8266\2.7.4\libraries\ESP8266WiFi\src/WiFiClientSecureBearSSL.h:150:28: error: expected '}' before end of line
 #pragma GCC diagnostic push
                            ^
Location: Line 150 of WiFiClientSecureBearSSL.h, another library file.
Problem: The compiler expected a closing brace (}) but hit a #pragma directive instead. This directive is used to control compiler warnings and is perfectly valid in the library. The error suggests the compiler thinks a block (e.g., a function or scope) is incomplete, which could stem from an issue in your sketch or a corrupted library.
Third Error:
C:\Users\Matthew Merrell\AppData\Local\Arduino15\packages\esp8266\hardware\esp8266\2.7.4\libraries\ESP8266WiFi\src/WiFiClientSecureBearSSL.h:150:28: error: expected declaration before end of line
Problem: The compiler reached the end of the file (or what it thinks is the end) without finding expected declarations, reinforcing the idea of a parsing failure.
General Observation:
The errors reference version 2.7.4 of the ESP8266 core (esp8266\hardware\esp8266\2.7.4), which is outdated as of March 13, 2025. The latest stable version is likely 3.1.2 or higher (3.1.2 was released in early 2023). This mismatch could contribute to compatibility issues with Arduino IDE 2.3.4.
The errors occur in library files, not your sketch directly, but the message "In function 'void setup()'" suggests the issue starts when parsing your setup() function in sketch_mar13b.ino.
Likely Causes
Syntax Error in Your Sketch:
A mistake in sketch_mar13b.ino (e.g., missing semicolon, unclosed brace, or malformed #include) could confuse the preprocessor, causing it to misinterpret the library files that follow.
Example: If you wrote #include <ESP8266WiFi.h (missing a closing >), the compiler might choke on the library’s extern "C" {.
Corrupted or Outdated ESP8266 Core:
Version 2.7.4 (from 2020) is old and might not play well with Arduino IDE 2.3.4 or your sketch’s requirements. Corruption during installation could also break the library files.
IDE or Cache Issue:
Arduino IDE 2.x sometimes caches files improperly, leading to strange compilation errors.
Steps to Fix
1. Share Your Sketch
The errors point to setup() in sketch_mar13b.ino, so the root cause might be in your code. Please paste the full contents of sketch_mar13b.ino here. Even a small typo could trigger this. For now, I’ll assume it starts with:
cpp
#include <ESP8266WiFi.h>
void setup() {
  // Something here causing trouble
}
void loop() {
}
2. Update the ESP8266 Core
Since you’re on 2.7.4, let’s update to the latest version:
Open Arduino IDE 2.3.4.
Go to Tools > Board > Boards Manager.
Search for esp8266.
If it shows "esp8266 by ESP8266 Community" with a version like 2.7.4 installed, select a newer version (e.g., 3.1.2 or later) from the dropdown and click Install.
If no newer version appears, ensure the URL https://arduino.esp8266.com/stable/package_esp8266com_index.json is in File > Preferences > Additional Boards Manager URLs (see my earlier answer for details).
After updating, try compiling again.
3. Check for Syntax Errors
Without your sketch, I can’t pinpoint the exact issue, but common culprits include:
Missing ; after a line in setup().
Unmatched { or }.
Incorrect #include syntax (e.g., <ESP8266WiFi.h instead of <ESP8266WiFi.h>).
Misspelled functions (e.g., wifi.begin() instead of WiFi.begin()).
Try a minimal sketch to test:
cpp
#include <ESP8266WiFi.h>
void setup() {
  Serial.begin(115200);
  WiFi.begin("yourSSID", "yourPassword");
}
void loop() {
}
Replace "yourSSID" and "yourPassword" with dummy values.
Compile this. If it works, the issue is in your original sketch.
4. Clear IDE Cache
If the library files are corrupted:
Close Arduino IDE.
Delete the folder: C:\Users\Matthew Merrell\AppData\Local\Arduino15.
Reopen the IDE, reinstall the ESP8266 package via Boards Manager, and try again.
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
JazzerAlto, 2025-03-18:
No issues for me with 2.3.4.

JazzerAlto, 2025-03-18:
How are you updating your libraries and board in IDE 2.3.4?  What board are you selecting in IDE?  Have you loaded WiFiManager 2.0.15-rc.1?  I used what is in IDE to add the board and libraries so not familiar with the process outlined in the link you included.

SumOfAMansLife, 2025-03-20:
For me it all started here: https://led-sectional.kyleharmon.com/?fbclid=IwAR2lp2Pbr6LbvlCvA8oq_ksaLXTrX4ITaUmJpdiETYpnUV-olX0iKRnIlJM
The link I posted in the first post was an attempt by someone else to clarify the software side of the instructions in Kyle's complete instructions.

Just a reminder, I have no idea what I am doing.

To directly answer your questions:
_How are you updating your libraries and board in IDE 2.3.4?_  esp 8266 core with version 2.7.4  and CH340G Driver. The FastLED I used is 3.4.0. (I used an older version on 2.0.3 IED). Someone posted an issue saying that anything after FastLED 3.4.0 did not work for them. Maybe I should use something older?

_What board are you selecting in IDE?_ WEMOS D1 Mini Lite.

_Have you loaded WiFiManager 2.0.15-rc.1?_ Never heard of it. I don't recall downloading this on my old laptop for version 2.0.3.

Thanks.

JazzerAlto, 2025-03-20:
Are you adding libraries and board support via the built in library and board management in IDE or trying to manually copy files to directories, etc?

Ignore my previous question about WiFiManager 2.0.15-rc.1.

SumOfAMansLife, 2025-03-24:
Everything except the CH340G driver were installed via IDE. In version 2.3.4 the option to add esp8266 only showed up when I plugged in the board into my computer. Otherwise I would only get the option install esp32 (or whatever it is). esp8266 will show up without the board plugged in for version 2.0.3.   CH340G had it's own install option.
(sorry for the delayed response. Been a bit busy. I appreciate the help.)

Closed 2025-09-26.

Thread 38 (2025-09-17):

aviationweather.gov/cgi-bin no longer support and has been removed

n251ea, 2025-09-17:
https://aviationweather.gov/data/api/#changes

/cgi-bin

    Unsupported — replaced by /api/data
    All references to cgi-bin have been removed and will no longer work
    Nearly all of the same services and options remain available through /api endpoints
    For example /cgi-bin/data/metar.php?ids=KSFO may be changed to /api/data/metar?ids=KSFO

old format -

https://aviationweather.gov/cgi-bin/data/dataserver.php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

returns:
  Status: "error"
  error "Not Found"

SM1516, 2025-09-17:
Hey!

It seems like I am having the same issue here as well. A few of them are turned off (close to 25% of them) and I am seeing "high wind" lights that do not match the actual METARs

ptader, 2025-09-17:
I'm wondering if this could be a problem with the FAA site and not the code. At one point the entire map turned purple, an indication of a communication problem. Not sure, but just want to add that info.

SM1516, 2025-09-18:
I agree, I don't think the code is the issue. This is what I am getting in the serial monitor, I may be wrong and I'm no expert, but it seems like the information it's pulling from the FAA website is wrong. For example, CYHM is really just 060@5 but the start of the line is showing 55G0 for some reason. In addition, it's missing a few airports. Hope this provides some insight to the solution!

---------------------------------------
Starting connection to server...
Connected ...
GET /api/data/dataserver?dataSource=metars&requestType=retrieve&format=xml&hoursBeforeNow=3&mostRecentForEachStation=true&stationString=WVFR,CYGK,CYTR,CYPQ,CYOO,CYQA,CYVV,CYYZ,CYTZ,CYSN,CYHM,CYKF,CYXU,CYZR,CYCK,CYQG HTTP/1.1
Host: aviationweather.gov
User-Agent: LED Map Client
Connection: close

Getting data
CYQG: VFR 5G0kts LED 20 WX: SPECI CYQG 180012Z AUTO 20005KT 9SM CLR 20/15 A3004 RMK SLP173 DENSITY ALT 1200FT
CYCK: VFR 5G0kts LED 19 WX: METAR CYCK 180000Z AUTO 24005KT 9SM CLR 19/16 A3003 RMK SLP171 DENSITY ALT 1200FT
CYGK: VFR 3G0kts LED 6 WX: METAR CYGK 180000Z 19003KT 15SM SCT240 18/14 A3002 RMK CI4 SLP170 DENSITY ALT 700FT
CYOO: VFR 2G0kts LED 9 WX: METAR CYOO 180000Z AUTO 08002KT 9SM CLR 18/14 A3003 RMK SLP171 DENSITY ALT 900FT
CYSN: VFR 0G0kts LED 14 WX: METAR CYSN 180000Z 00000KT 15SM SCT250 18/17 A3001 RMK CI4 SLP165 DENSITY ALT 700FT
CYTZ: VFR 3G0kts LED 13 WX: METAR CYTZ 180000Z AUTO 10003KT 060V130 9SM CLR 19/18 A3002 RMK SLP167 DENSITY ALT 700FT
CYXU: VFR 6G0kts LED 17 WX: METAR CYXU 180000Z 32006KT 15SM FEW280 22/11 A3003 RMK CI1 CI TR SLP171 DENSITY ALT 1800FT
CYYZ: VFR 6G0kts LED 12 WX: METAR CYYZ 180000Z 15006KT 15SM FEW250 20/16 A3002 RMK CI2 SLP168 DENSITY ALT 1200FT
CYVV: VFR 0G0kts LED 11 WX: METAR CYVV 180000Z 00000KT 15SM FEW250 17/14 A3002 RMK CI1 SLP171 DENSITY ALT 1000FT
**CYHM: VFR 55G0kts** LED 15 WX: METAR CYHM 180000Z 06005KT 15SM SCT240 19/14 A3003 RMK CI3 SLP170 DENSITY ALT 1400FT
... found very high winds or gusts!
CYPQ: VFR 3G0kts LED 8 WX: METAR CYPQ 180000Z AUTO 24003KT 9SM CLR 16/14 A3003 RMK SLP173
CYQA: VFR 6G0kts LED 10 WX: METAR CYQA 180000Z AUTO 30006KT 9SM CLR 21/13 A3002 RMK SLP170 DENSITY ALT 1700FT
CYTR:  0G0kts LED 7 WX: METAR CYTR 180000Z 21003KT 15SM FEW070 SCT240 OVC270 19/13 A3001 RMK AC1CI4CS4 DENSITY ALT 926FT CIG PDMTLY TRANSPARENT SLP165
Refreshing LEDs.
There is lightning, thunderstorms or high wind, or we're using a light sensor, so no long sleep.
# LEDs with high winds or gusts: 0
# LEDs with very high winds or gusts: 1
# LEDs with thunderstorms or lightning: 0
# LEDs with snow: 0
Light reading: 958.00 raw, 30 brightness
Loop 1 of 75

n251ea, 2025-09-18:
for anybody using the fork "jcl-rv12is" after some tinkering, the only thing that needs to be done is remove line 493 which is

`        if (c == '\n') currentLine = "";
`

this port was keying on an entry in the XML code of the <raw_text> to identify changes in airports vs the modification above added the check to look for "<METAR>".  I think both will work fine.

CrazyProduceGuy, 2025-09-18:
When I paste **rixceu**'s code in, the Arduino won't compile.  I get an error that reads

_cannot convert 'String' to 'int'_

And it highlights the doColor line that **n251ea** tweaked.  Even using that amended code, I still get the same error.

On a lark, I also tweaked the sourcing code to read,

#define SERVER "aviationweather.gov"
#define BASE_URI "/api/data/metar?format=xml&ids="

(Instead of the longer code.)

None of these three fixed did anything.  I still have a sad, black LED map.

This isn't something I'm great at.  Kyle's code is awesome, but I used it to make LED maps that pull the temperature and lightning information out.  In this way, I have several large maps that provide temperature data across a region.  (Or did, until AviationWeather once again changed their code ... now they're just black maps that make my wall sad!  Lol.)

Any help with this error or refreshing the original code would be very helpful as these fixes didn't achieve anything,

Thanks, all.

n251ea, 2025-09-18:
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

I am assuming you are using Kyle's original code, if that is correct then you want to look for this line -

`while (client.connected()) {`

then delete everything from that line down and including the three braces:

'    }
  }
}
'

next replace what you just removed with the code that rixceu posted above (make sure you put it in the right location!  NOTE rixceu renamed a variable and called it "led_status_mode = true;", you will find it right above the three braces, I believe you want to make this "ledStatus = true;" otherwise the program will not compile.

CrazyProduceGuy, 2025-09-19:
I appreciate the help n251ea.  I am, indeed, using Kyle's code -- albeit formatted a bit towards the end to have colors change because of the temperature and not the ceiling height.  But that's never had an issue before so it has to be somewhere in the parsing of the data.

Starting with a clean bit of the code that definitely worked before, I started over.  First, I checked to be sure that the code compiled, and was loaded, with just the cgi-bin/data to api/data change.  No issues at all, just the same blank LEDs due to the likely overload of the ESP's memory.

I then followed your instructions, which essentially deletes everything between
     _Serial.println();_

and

 _// need to doColor this for the last airport
  for (vector<unsigned short int>::iterator it = led.begin(); it != led.end(); ++it) {_

I compiled the code and still get the same error at the same doColor line.  There is something in that line of code that fails some a string to integer conversion.  It is not at all clear what, and it definitely seems odd that my file appears to be an outlier, especially given everyone else's success with that tweak.  (I also changed the ledStatus bit, though unsurprisingly that made no difference,)

I'm open to other suggestions, but I really appreciate the help you offered even if it wasn't successful.

CrazyProduceGuy, 2025-09-26:
I know this is marked closed, but even with the refinements to the code noted -- both from WKHarmon and rixceu -- my map still goes to black.  It doesn't seem to parse data ... or even gather it as best as I can tell.  As I noted elsewhere, the code was tweaked a bit to have the map show temperature gradients (and flash with lightning in the area).  It made a nice visual display and worked perfectly fine until whatever changed with the code in the past week.

To the best of my ability I believe I've captured all of the changes made, but the map just goes to black.  The COM reader seems to imply that nothing's happening.  But each of the weather stations is valid and broadcasting data when I plug it into the browser on a line-by-line basis.

From the COM reader:
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

This is the raw code.  Any help would be really appreciated.  It has to be something stupidly minor, but while I can read code pretty well, actually programming it is a different skillset that I lack.  Any help is deeply appreciated.  I actually have four of these suckers: one for the Outer Banks area, one for the entirety of the world, and two regional ones.  They're fun pieces for my office.

`#include <ESP8266WiFi.h>
#include <FastLED.h>
#include <WiFiManager.h>
#include <vector>
using namespace std;

#define FASTLED_ESP8266_RAW_PIN_ORDER

#define NUM_AIRPORTS 50 // This is really the number of LEDs
#define WIND_THRESHOLD 25 // Maximum windspeed for green, otherwise the LED turns yellow
#define LOOP_INTERVAL 2500 // ms - interval between brightness updates and lightning strikes
#define DO_LIGHTNING true // Lightning uses more power, but is cool.
#define DO_WINDS false // color LEDs for high winds
// #define REQUEST_INTERVAL 900000 // How often we update. In practice LOOP_INTERVAL is added. In ms (15 min is 900000)
 #define REQUEST_INTERVAL 300000 // How often we update. In practice LOOP_INTERVAL is added. In ms (15 min is 900000)

#define USE_LIGHT_SENSOR false // Set USE_LIGHT_SENSOR to true if you're using any light sensor.
// Set LIGHT_SENSOR_TSL2561 to true if you're using a TSL2561 digital light sensor.
// Kits shipped after March 1, 2019 have a digital light sensor. Setting this to false assumes an analog light sensor.
#define LIGHT_SENSOR_TSL2561 false

// const char ssid[] = HIDDEN
// const char pass[] = HIDDEN

// Define the array of leds
CRGB leds[NUM_AIRPORTS];
#define DATA_PIN    D4 // Kits shipped after March 1, 2019 should use 14. Earlier kits us 5.
#define LED_TYPE    WS2811
#define COLOR_ORDER RGB
#define BRIGHTNESS 15 // 20-30 recommended. If using a light sensor, this is the initial brightness on boot.
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
timmyjane, 2025-09-26:
You probably have updated your libraries. Make sure ESP8266 is on 2.7.4 and FastLEDs is on 3.4.0.
Mine is working but some stations are black.  Going to let it run for a while and see if it fixes itself.

TiVoHomeUser, 2025-09-27:
CrazyProduceGuy, Another issue

You are checking the airports identifier string for the status
std::vector<String> airports({
  "NULL", // 0
  "KOAJ", // 1, Jacksonville NC
  "KNCA", // 2, New River NC
  "NULL", // 3,
  "KNJM", // 4, Bogue Field NC
  "NULL", // 5,

 Your code is comparing the station identifier "NULL" or "KOAJ" etc with the meteorology condition "VFR" "WVFR ...  not useful here.

// Do the key LEDs now if they exist
  for (int i = 0; i < (NUM_AIRPORTS); i++) {
    // Use this opportunity to set colors for LEDs in our key then build the request string
    if (airports[i] == "VFR") leds[i] = CRGB::Green;
    else if (airports[i] == "WVFR") leds[i] = CRGB::Yellow;
    else if (airports[i] == "MVFR") leds[i] = CRGB::Blue;
    else if (airports[i] == "IFR") leds[i] = CRGB::Magenta;
    else if (airports[i] == "LIFR") leds[i] = CRGB::Red;
  }

My guess would be you want to change that to
// Do the key LEDs now if they exist
  for (int i = 0; i < (NUM_AIRPORTS); i++) {
    // Use this opportunity to set colors for LEDs in our key then build the request string
    	 if (airports[i] == "NULL") leds[i] = CRGB::Black;     // turn off the stations that do not exist
    else if (currentCondition == "VFR") leds[i] = CRGB::Green;
    else if (currentCondition == "WVFR") leds[i] = CRGB::Yellow;
    else if (currentCondition == "MVFR") leds[i] = CRGB::Blue;
    else if (currentCondition == "IFR") leds[i] = CRGB::Magenta;
    else if (currentCondition == "LIFR") leds[i] = CRGB::Red;
}

Closed 2025-09-26.

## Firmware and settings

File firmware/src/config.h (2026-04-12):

#ifndef CONFIG_H
#define CONFIG_H

#include <Arduino.h>
#include <vector>

// Configuration version - increment when schema changes
#define CONFIG_VERSION 2

// Hardware defaults
#define DEFAULT_DATA_PIN 14
#define DEFAULT_NUM_LEDS 80
#define DEFAULT_BRIGHTNESS 20
#define DEFAULT_LED_TYPE "WS2811"
#define DEFAULT_COLOR_ORDER "RGB"

// Timing defaults (milliseconds)
#define DEFAULT_REQUEST_INTERVAL 900000  // 15 minutes
#define DEFAULT_LOOP_INTERVAL 5000       // 5 seconds
#define DEFAULT_WIFI_TIMEOUT 60          // seconds
#define DEFAULT_READ_TIMEOUT 15          // seconds

// Feature defaults
#define DEFAULT_WIND_THRESHOLD 25
#define DEFAULT_DO_LIGHTNING true
#define DEFAULT_DO_WINDS true
#define DEFAULT_WIND_ALTERNATE false
#define DEFAULT_WIND_ALTERNATE_INTERVAL 2000  // milliseconds (1-10 seconds)

// Light sensor defaults
#define DEFAULT_USE_LIGHT_SENSOR false
#define DEFAULT_MIN_BRIGHTNESS 20
#define DEFAULT_MAX_BRIGHTNESS 30
#define DEFAULT_MIN_LIGHT 16
#define DEFAULT_MAX_LIGHT 30

// MQTT defaults
#define DEFAULT_MQTT_ENABLED false
#define DEFAULT_MQTT_BROKER ""
#define DEFAULT_MQTT_PORT 1883
#define DEFAULT_MQTT_USERNAME ""
#define DEFAULT_MQTT_PASSWORD ""
#define DEFAULT_POWER_ON true
#define DEFAULT_NO_DATA_COLOR "#000000"  // Black (LED off) when no weather data

// WiFi reset button
#define WIFI_RESET_PIN 12  // GPIO12 (D6 on D1 Mini)

// Light sensor type enumeration
enum LightSensorType {
    LIGHT_SENSOR_NONE = 0,
    LIGHT_SENSOR_ANALOG = 1,
    LIGHT_SENSOR_TSL2561 = 2
};

// Main configuration structure
struct Config {
    int version;

    // Airport list - can hold up to 150+ airports
    std::vector<String> airports;

    // LED hardware settings
    int dataPin;
    int brightness;
    String ledType;
    String colorOrder;

    // Timing settings
    unsigned long requestInterval;
    unsigned long loopInterval;

    // Feature toggles
    int windThreshold;
    bool doLightning;
    bool doWinds;
    bool windAlternate;  // Alternate between category color and yellow for windy airports
    unsigned long windAlternateInterval;  // Milliseconds between color switches (1000-10000)

    // Light sensor settings
    bool useLightSensor;
    LightSensorType lightSensorType;
    int minBrightness;
    int maxBrightness;
    int minLight;
    int maxLight;

    // MQTT settings
    bool mqttEnabled;
    String mqttBroker;
    uint16_t mqttPort;
    String mqttUsername;
    String mqttPassword;

    // Power state (controlled via MQTT or web)
    bool powerOn;

    // Color for airports with no weather data (hex string, e.g. "#FFFFFF")
    String noDataColor;

    // Constructor with defaults
    Config() {
        version = CONFIG_VERSION;
        dataPin = DEFAULT_DATA_PIN;
        brightness = DEFAULT_BRIGHTNESS;
        ledType = DEFAULT_LED_TYPE;
        colorOrder = DEFAULT_COLOR_ORDER;
        requestInterval = DEFAULT_REQUEST_INTERVAL;
        loopInterval = DEFAULT_LOOP_INTERVAL;
        windThreshold = DEFAULT_WIND_THRESHOLD;
        doLightning = DEFAULT_DO_LIGHTNING;
        doWinds = DEFAULT_DO_WINDS;
        windAlternate = DEFAULT_WIND_ALTERNATE;
        windAlternateInterval = DEFAULT_WIND_ALTERNATE_INTERVAL;
        useLightSensor = DEFAULT_USE_LIGHT_SENSOR;
        lightSensorType = LIGHT_SENSOR_NONE;
        minBrightness = DEFAULT_MIN_BRIGHTNESS;
        maxBrightness = DEFAULT_MAX_BRIGHTNESS;
        minLight = DEFAULT_MIN_LIGHT;
        maxLight = DEFAULT_MAX_LIGHT;
        mqttEnabled = DEFAULT_MQTT_ENABLED;
        mqttBroker = DEFAULT_MQTT_BROKER;
        mqttPort = DEFAULT_MQTT_PORT;
        mqttUsername = DEFAULT_MQTT_USERNAME;
        mqttPassword = DEFAULT_MQTT_PASSWORD;
        powerOn = DEFAULT_POWER_ON;
        noDataColor = DEFAULT_NO_DATA_COLOR;
    }

    // Get number of LEDs (derived from airports size)
    int getNumLeds() const {
        return airports.size();
    }
};

// Configuration management functions
bool configInit();
bool configLoad(Config& config);
bool configSave(const Config& config);
void configSetDefaults(Config& config);
String configToJson(const Config& config);
bool configFromJson(const String& json, Config& config);

// Get the global configuration instance
Config& getConfig();

#endif // CONFIG_H

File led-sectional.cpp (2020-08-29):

#include <ESP8266WiFi.h>
#include <FastLED.h>
#include <WiFiManager.h>
#include <ESP8266WebServer.h>
#include <DNSServer.h>
#include <vector>
#include <map>
using namespace std;

#define WIND_THRESHOLD 25 // Maximum windspeed for green
#define LIGHTNING_INTERVAL 5000 // ms - how often should lightning strike; not precise because we sleep in-between
#define DO_LIGHTNING true // Do lightning flashes when there is nearby thunderstorms
#define DO_WINDS true // color LEDs for high winds
#define BRIGHTNESS 20 // LED brightness
#define USE_LIGHT_SENSOR false // Set USE_LIGHT_SENSOR to true if you're using any light sensor.
// Set LIGHT_SENSOR_TSL2561 to true if you're using a TSL2561 digital light sensor.
// Kits shipped after March 1, 2019 have a digital light sensor. Setting this to false assumes an analog light sensor.
#define LIGHT_SENSOR_TSL2561 true

#define REQUEST_INTERVAL 900000 // how often to update in ms (15 min is 900000)

std::vector<String> airports({
  "LIFR", // 1 order of LEDs, starting with 1 should be KKIC; use VFR, WVFR, MVFR, IFR, LIFR for key; NULL for no airport
  "IFR", // 2
  "MVFR", // 3
  "WVFR", // 4
  "VFR", // 5
  "NULL", // 6
  "NULL", // 7
  "KMRY", // 8
  "KSNS", // 9
  "KCVH", // 10
  "KWVI", // 11
  "KE16", // 12
  "KRHV", // 13
  "KSJC", // 14
  "KNUQ", // 15
  "KPAO", // 16
  "KSQL", // 17
  "KHAF", // 18
  "KSFO", // 19
  "KOAK", // 20
  "KHWD", // 21
  "KLVK", // 22
  "KC83", // 23
  "NULL", // 24
  "KCCR", // 25
  "NULL", // 26
  "KDVO", // 27
  "KO69", // 28
  "KSTS", // 29
  "NULL", // 30
  "KAPC", // 31
  "KSUU", // 32
  "KVCB", // 33
  "KEDU", // 34
  "KSMF", // 35
  "KSAC", // 36
  "KMHR", // 37
  "KMCC", // 38
  "KLHM", // 39
  "KMYV", // 40
  "KBAB", // 41
  "NULL", // 42
  "KOVE", // 43
  "NULL", // 44
  "KCIC", // 45
  "NULL", // 46
  "KRBL", // 47
  "NULL", // 48
  "NULL", // 49
  "NULL", // 50
  "KGOO", // 51
  "KBLU", // 52
  "NULL", // 53
  "KTRK", // 54
  "KRNO", // 55
  "KCXP", // 56
  "KMEV", // 57
  "KTVL", // 58
  "NULL", // 59
  "NULL", // 60
  "KAUN", // 61
  "KPVF", // 62
  "KJAQ", // 63
  "KCPU", // 64
  "KO22", // 65
  "NULL", // 66
  "NULL", // 67
  "KSCK", // 68
  "KTCY", // 69
  "NULL", // 70
  "KMOD", // 71
  "NULL", // 72
  "KMER", // 73
  "MKCE", // 74
  "NULL", // 75
  "KMAE", // 76
  "NULL", // 77
  "KFAT", // 78
  "NULL", // 79
  "KNLC" // 80
});

/* This section only applies if you have an ambient light sensor connected */
#if USE_LIGHT_SENSOR
/* The sketch will automatically scale the light between MIN_BRIGHTNESS and
MAX_BRIGHTNESS on the ambient light values between MIN_LIGHT and MAX_LIGHT
Set MIN_BRIGHTNESS and MAX_BRIGHTNESS to the same value to achieve a simple on/off effect. */
#define MIN_BRIGHTNESS 20 // Recommend values above 4 as colors don't show well below that
#define MAX_BRIGHTNESS 20 // Recommend values between 20 and 30

// Light values are a raw reading for analog and lux for digital
#define MIN_LIGHT 16 // Recommended default is 16 for analog and 2 for lux
#define MAX_LIGHT 30 // Recommended default is 30 to 40 for analog and 20 for lux

#if LIGHT_SENSOR_TSL2561
#include <Adafruit_Sensor.h>
#include <Adafruit_TSL2561_U.h>
#include <Wire.h>
Adafruit_TSL2561_Unified tsl = Adafruit_TSL2561_Unified(TSL2561_ADDR_FLOAT, 12345);
#else
#define LIGHTSENSORPIN A0 // A0 is the only valid pin for an analog light sensor
#endif

#endif
/* ----------------------------------------------------------------------- */

// You usually shouldn't need to edit anything below this.

#define FASTLED_ESP8266_RAW_PIN_ORDER
int status = WL_IDLE_STATUS;
#define READ_TIMEOUT 15 // Cancel query if no data received (seconds)
#define WIFI_TIMEOUT 60 // in seconds
#define RETRY_TIMEOUT 15000 // in ms
#define SERVER "www.aviationweather.gov"
#define BASE_URI "/adds/dataserver_current/httpparam?dataSource=metars&requestType=retrieve&format=xml&hoursBeforeNow=3&mostRecentForEachStation=false&stationString="
#define DEBUG false
#define PROGRAM_PIN 12
#define CONFIG_SSID "LED-Sectional"
#define CONFIG_PASS "metar123"

// Define the array of leds
CRGB* leds;
#define DATA_PIN 14 // new kits should use 14; old ones use 5
#define LED_TYPE WS2811
#define COLOR_ORDER RGB

class AirportState {
 public:
 AirportState() {
  condition_=NONE;
  wind_=0;
  gusts_=0;
  lightning_=false;
 }
  String observation_time_;
  String iaco_;
  void setCategory(const String& cat) {
    if (cat == "VFR") {
      condition_ = VFR;
    }
    if (cat == "MVFR") {
      condition_ = MVFR;
    }
    if (cat == "IFR") {
      condition_ = IFR;
    }
    if (cat == "LIFR") {
      condition_ = LIFR;
    }
  }
  void setWind(const String& w) {
    wind_ = w.toInt();
  }
  void setGust(const String& w) {
    gusts_ = w.toInt();
  }

  bool complete() {
    if (condition_ == NONE) {
      Serial.println("missing condition");
    }
    if (time_.length() == 0) {
      Serial.println("time");
      
    }
    if (iaco_.length() == 0) {
      Serial.println("iaco");
    }
    return condition_ != NONE && time_.length() != 0 && iaco_.length() != 0;
  }

  CRGB getColor() {
    if (lightning_ && (millis() % LIGHTNING_INTERVAL < 50)) {
      return CRGB::White;
    }
    CRGB color;
    if (condition_ ==LIFR) color = CRGB::Magenta;
    else if (condition_ == IFR) color = CRGB::Red;
    else if (condition_ == MVFR) color = CRGB::Blue;
    else if (condition_ == VFR) {
      if ((wind_ > WIND_THRESHOLD || gusts_ > WIND_THRESHOLD) && DO_WINDS) {
        color = CRGB::Yellow;
      } else {
        color = CRGB::Green;
      }
    } else color = CRGB::Black;
  
    return color;
  }

  String condition() {
    switch (condition_) {
      case VFR: return "VFR";
      case MVFR: return "MVFR";
      case IFR: return "IFR";
      case LIFR: return "LIFR";
    }
    return "Unknown";
  }

  String wind() {
    return String(wind_, DEC);
  }

  String gust() {
    return String(gusts_, DEC);
  }
  
  enum {
    NONE,
    VFR,
    MVFR,
    IFR,
    LIFR
  } condition_;
  int wind_;
  int gusts_;
  String time_;
  bool lightning_;
};

class SSLBuffer {
  public:
  SSLBuffer(BearSSL::WiFiClientSecure* client) {
    client_ = client;
    i_=0;
    total_read_=0;
  }
  int connected() {
    return client_->connected();
  }
  char read() {
    yield();
    if (i_ >= total_read_) {
      i_ = 0;
    }
    if (i_ == 0) {
      total_read_ = client_->read(buffer_, 512);
    }
    return buffer_[i_++];
  }
  BearSSL::WiFiClientSecure* client_;
  int i_;
  int total_read_;
  uint8_t buffer_[512];
};

std::map<String, AirportState> wx;

String airportString;

bool readNextFmt(SSLBuffer* client, const char* f, String* result) {
  const char* startover = f;
  bool copying = false;
  char c;
  for (; *f && client->connected() && (c=client->read());) {
    if (*f == 'X') {
      copying = true;
      f++;
    }
    if (c == *f) {
      f++;
      copying = false;
    } else if (copying) {
      *result += c;
    } else {
      // start over
      f=startover;
      copying=false;
      *result=String();
    }
  }
  if (*f == '\0') {
    return true;
  }
  
  return false;
}

AirportState getAirportState(SSLBuffer* client) {
  AirportState ret;
  String token;
  bool found_station= false;
  for (; readNextFmt(client, "<X>", &token);) {
    if (token == "/METAR") {
      break;
    }
    if (token == "station_id") {
      readNextFmt(client, "X<", &ret.iaco_);
      if (found_station) {
        Serial.println("Found station twice " + ret.iaco_); 
      }
      found_station = true;
    }
    if (token == "flight_category") {
      String category;
      readNextFmt(client, "X<", &category);
      ret.setCategory(category);
    }
    if (token == "observation_time") {
      readNextFmt(client, "X<", &ret.time_);
    }
    if (token == "wind_speed_kt") {
      String w;
      readNextFmt(client, "X<", &w);
      ret.setWind(w);
    }
    if (token == "wind_gust_kt") {
      String w;
      readNextFmt(client, "X<", &w);
      ret.setGust(w);
    }
    if (token == "wx_string") {
      String w;
      readNextFmt(client, "X<", &w);
      int ts_idx = w.indexOf("TS");
      if (ts_idx != -1) {
        ret.lightning_ = true;
      }
    }
  }
  return ret;
}

#if USE_LIGHT_SENSOR
void adjustBrightness() {
  byte brightness;
  float reading;

  #if LIGHT_SENSOR_TSL2561
  sensors_event_t event;
  tsl.getEvent(&event);
  reading = event.light;
  #else
  reading = analogRead(LIGHTSENSORPIN);
  #endif

  if (reading <= MIN_LIGHT) brightness = 0;
  else if (reading >= MAX_LIGHT) brightness = MAX_BRIGHTNESS;
  else {
    // Percentage in lux range * brightness range + min brightness
    float brightness_percent = (reading - MIN_LIGHT) / (MAX_LIGHT - MIN_LIGHT);
    brightness = brightness_percent * (MAX_BRIGHTNESS - MIN_BRIGHTNESS) + MIN_BRIGHTNESS;
  }

  FastLED.setBrightness(brightness);
}
#endif

#define LINE_BUFFER_SIZE 300
bool getMetars() {
  digitalWrite(LED_BUILTIN, LOW);
  //lightningLeds.clear(); // clear out existing lightning LEDs since they're global
  //fill_solid(leds, airports.size(), CRGB::Black); // Set everything to black just in case there is no report
  uint32_t t;
  
  BearSSL::WiFiClientSecure client;
  client.setInsecure();
  //Serial.println("\nStarting connection to server...");
  // if you get a connection, report back via serial:
  if (!client.connect(SERVER, 443)) {
    Serial.println("Connection failed!");
    client.stop();
    return false;
  } else {
    Serial.println("Connected ...");
    Serial.print("GET ");
    Serial.print(BASE_URI);
    Serial.print(airportString);
    Serial.println(" HTTP/1.1");
    Serial.print("Host: ");
    Serial.println(SERVER);
    Serial.println("Connection: close");
    Serial.println();
    // Make a HTTP request, and print it to console:
    client.print("GET ");
    client.print(BASE_URI);
    client.print(airportString);
    client.println(" HTTP/1.1");
    client.print("Host: ");
    client.println(SERVER);
    client.println("Connection: close");
    client.println();
    client.flush();
    t = millis(); // start time
    FastLED.clear();

    //Serial.println("Getting data");

    while (!client.connected()) {
      if ((millis() - t) >= (READ_TIMEOUT * 1000)) {
        Serial.println("---Timeout---");
        client.stop();
        return false;
      }
      Serial.print(".");
      delay(1000);
    }

    Serial.println("parsing data");
    SSLBuffer client_wrapper(&client);

    wx.clear();
    wx["VFR"].condition_=AirportState::VFR;
    wx["IFR"].condition_=AirportState::IFR;
    wx["LIFR"].condition_=AirportState::LIFR;
    wx["MVFR"].condition_=AirportState::MVFR;
    wx["WVFR"].condition_=AirportState::VFR;
    wx["WVFR"].wind_=WIND_THRESHOLD + 1;
    while (client.connected()) {
      String tmp;
      if (readNextFmt(&client_wrapper, "<METAR>", &tmp)) {
          AirportState state = getAirportState(&client_wrapper);
          if (state.complete() && wx[state.iaco_].time_ < state.time_) {
            wx[state.iaco_]=state;
          }
        }
    }
    Serial.println("done");
    digitalWrite(LED_BUILTIN, HIGH);
  }

  // Dump results
  for (unsigned int i = 0; i < airports.size(); ++i) {
    AirportState& as = wx[airports[i]];
    Serial.println(airports[i] + " " + as.iaco_ + " " + as.time_ + " " + as.condition() + " " + as.wind() + " " + as.gust());
  }
  client.stop();
  return true;
}

void configModeCallback (WiFiManager *myWiFiManager) {
  fill_solid(leds, airports.size(), CRGB::Red); // Red means we're in config mode
  FastLED.show();
}

void setup() {
  //Initialize serial and wait for port to open:
  Serial.begin(74880);

  pinMode(PROGRAM_PIN, INPUT_PULLUP);
  pinMode(LED_BUILTIN, OUTPUT); // give us control of the onboard LED
  digitalWrite(LED_BUILTIN, LOW);

  leds=new CRGB[airports.size()];

  // Initialize LEDs
  FastLED.addLeds<LED_TYPE, DATA_PIN, COLOR_ORDER>(leds, airports.size());
  FastLED.setBrightness(BRIGHTNESS);

  bool firstAirport = true;
  for (unsigned int i = 0; i < airports.size(); i++) {
    if (airports[i] != "NULL" && airports[i] != "VFR" && airports[i] != "MVFR" && airports[i] != "WVFR" && airports[i] != "IFR" && airports[i] != "LIFR") {
      if (firstAirport) {
        firstAirport = false;
        airportString = airports[i];
      } else {
        airportString = airportString + "," + airports[i];
      }
    }
  }

  fill_solid(leds, airports.size(), CRGB::Orange); // indicate status with LEDs
  FastLED.show();

  WiFiManager wifiManager;
  wifiManager.setAPCallback(configModeCallback);
  wifiManager.setConfigPortalTimeout(180);
  wifiManager.autoConnect(CONFIG_SSID, CONFIG_PASS);

  fill_solid(leds, airports.size(), CRGB::Purple); // indicate status with LEDs
  FastLED.show();
}

unsigned long last_update = 0;
void loop() {
  #if USE_LIGHT_SENSOR
  adjustBrightness();
  #endif

  if ( digitalRead(PROGRAM_PIN) == LOW ) {
    WiFiManager wifiManager;
    wifiManager.resetSettings();
    ESP.restart();
  }

  if (last_update == 0 || (millis() > (last_update + REQUEST_INTERVAL))) {
    getMetars();
    last_update = millis();
  }
  for (unsigned int i = 0; i < airports.size(); ++i) {
    leds[i]=wx[airports[i]].getColor();
  }
  FastLED.show();
}

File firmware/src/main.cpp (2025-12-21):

/**
 * LED Sectional v2.0
 *
 * Aviation weather display using WS2811 LEDs and ESP8266
 * Fetches METAR data and displays flight categories on a sectional map
 *
 * Features:
 * - WiFiManager for easy WiFi configuration
 * - Streaming JSON parser for memory-efficient METAR parsing
 * - Web Serial configuration via browser
 * - Support for 150+ airports
 * - Lightning animation for thunderstorms
 * - Optional light sensor for automatic brightness
 *
 * Repository: https://github.com/WKHarmon/led-sectional
 */

#include <Arduino.h>
#include "config.h"
#include "wifi_manager.h"
#include "metar.h"
#include "leds.h"
#include "light_sensor.h"
#include "serial_cmd.h"
#include "mqtt.h"

// State tracking
static unsigned long lastMetarFetch = 0;
static bool initialFetchDone = false;
static bool ledStatusShown = false;

// Callback for METAR data processing
void onMetarReceived(const String& icao, int ledIndex, const String& fltCat,
                     int wspd, int wgst, const String& wxString) {
    Config& config = getConfig();

    // Log the METAR
    Serial.printf("%s: %s %dG%d kts LED %d", icao.c_str(), fltCat.c_str(), wspd, wgst, ledIndex);

    // Check for thunderstorm
    if (wxString.indexOf("TS") >= 0) {
        Serial.print(" [LIGHTNING]");
        ledsAddLightning(ledIndex);
    }
    Serial.println();

    // Set the LED color based on flight category
    ledsSetFlightCategory(ledIndex, fltCat, wspd, wgst);
}

void setup() {
    // Initialize serial first for debugging
    serialCmdInit();
    Serial.println();
    Serial.println("========================================");
    Serial.println("LED Sectional v2.0 Starting...");
    Serial.println("========================================");

    // Initialize filesystem and load configuration
    if (!configInit()) {
        Serial.println("FATAL: Failed to initialize filesystem");
        // Continue anyway, will use defaults
    }

    Config& config = getConfig();
    if (!configLoad(config)) {
        Serial.println("Using default configuration");
    }

    Serial.printf("Configuration: %d airports, brightness %d\n",
                  config.airports.size(), config.brightness);

    // Initialize LEDs
    ledsInit();
    ledsSetAll(COLOR_WIFI_CONNECTING);
    ledsShow();

    // Initialize WiFi
    pinMode(LED_BUILTIN, OUTPUT);
    digitalWrite(LED_BUILTIN, LOW);  // LED on during startup

    // Check if this is a fresh device (no saved WiFi credentials)
    // If so, wait indefinitely for serial configuration - no AP mode fallback
    // AP mode is only used when saved credentials fail to connect
    if (!wifiHasSavedCredentials()) {
        Serial.println("No saved WiFi credentials - waiting for serial configuration");
        Serial.println("Connect via Web Serial to configure WiFi");

        // Wait indefinitely for serial WiFi configuration
        // Device will reboot when credentials are set via set_wifi command
        while (true) {
            serialCmdProcess();

            // Blink LED to indicate waiting for config
            static unsigned long lastBlink = 0;
            if (millis() - lastBlink > 500) {
                digitalWrite(LED_BUILTIN, !digitalRead(LED_BUILTIN));
                lastBlink = millis();
            }

            delay(10);
            yield();
        }
    }

    if (!wifiInit()) {
        Serial.println("WiFi initialization failed - continuing anyway");
        ledsSetAll(COLOR_FETCH_ERROR);
        ledsShow();
    } else {
        ledsSetAll(COLOR_WIFI_CONNECTED);
        ledsShow();
        delay(500);
    }

    // Initialize light sensor if enabled
    if (config.useLightSensor) {
        lightSensorInit();
    }

    // Initialize METAR fetching
    metarInit();

    // Initialize MQTT for Home Assistant integration
    mqttInit();

    // Apply saved power state
    if (!config.powerOn) {
        ledsSetPower(false);
        Serial.println("Power state: OFF (from saved config)");
    }

    digitalWrite(LED_BUILTIN, HIGH);  // LED off, startup complete

    Serial.printf("Setup complete (free heap: %d bytes)\n", ESP.getFreeHeap());
    Serial.println("========================================");
}

void loop() {
    Config& config = getConfig();
    unsigned long currentTime = millis();

    // Process serial commands (from web interface)
    serialCmdProcess();

    // Check for WiFi reset button
    if (wifiCheckResetButton()) {
        Serial.println("WiFi reset requested via button");
        ledsSetAll(COLOR_WIFI_CONNECTING);
        ledsShow();
        wifiStartConfigPortal();
    }

    // Reconnect WiFi if disconnected
    if (!wifiIsConnected()) {
        if (!ledStatusShown) {
            ledsSetAll(COLOR_WIFI_CONNECTING);
            ledsShow();
            ledStatusShown = true;
        }

        // Try to reconnect
        if (!wifiInit()) {
            delay(5000);  // Wait before retry
            return;
        }

        ledStatusShown = false;
        ledsSetAll(COLOR_WIFI_CONNECTED);
        ledsShow();
        delay(500);
    }

    // MQTT loop - handles connection and message processing
    mqttLoop();

    // Skip display updates if power is off
    if (!config.powerOn) {
        // Still need to process serial and MQTT, but skip LED updates
        unsigned long waitStart = millis();
        while (millis() - waitStart < config.loopInterval) {
            serialCmdProcess();
            mqttLoop();
            delay(10);
            yield();
        }
        return;
    }

    // Adjust brightness if light sensor is enabled
    if (lightSensorIsEnabled()) {
        lightSensorAdjustBrightness();
    }

    // Lightning animation
    if (config.doLightning && ledsHasLightning()) {
        ledsDoLightning();
    }

    // Wind alternation animation (alternates between category color and yellow)
    if (config.windAlternate && ledsHasWindy()) {
        ledsDoWindAlternate();
    }

    // Determine if we should fetch METARs
    bool shouldFetch = false;

    if (!initialFetchDone) {
        // First fetch after boot
        shouldFetch = true;
    } else if (currentTime - lastMetarFetch >= config.requestInterval) {
        // Regular interval fetch
        shouldFetch = true;
    } else if (serialCmdCheckForceFetch()) {
        // Forced fetch via serial command
        shouldFetch = true;
    }

    if (shouldFetch && wifiIsConnected()) {
        Serial.println();
        Serial.println("----------------------------------------");
        Serial.println("Fetching METAR data...");

        digitalWrite(LED_BUILTIN, LOW);  // LED on during fetch

        // Clear lightning and windy lists, then clear LEDs before fetch
        ledsClearLightning();
        ledsClearWindy();
        ledsClear();

        // Check if there are any real airports to fetch
        String airportString = metarBuildAirportString();
        bool fetchSuccess = false;
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

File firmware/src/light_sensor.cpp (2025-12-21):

#include "light_sensor.h"
#include "config.h"
#include "leds.h"

// Conditionally include TSL2561 library
#include <Wire.h>
#include <Adafruit_Sensor.h>
#include <Adafruit_TSL2561_U.h>

// TSL2561 sensor instance
static Adafruit_TSL2561_Unified* tsl = nullptr;
static bool sensorAvailable = false;

void lightSensorInit() {
    Config& config = getConfig();

    if (!config.useLightSensor) {
        sensorAvailable = false;
        Serial.println("Light sensor disabled");
        return;
    }

    if (config.lightSensorType == LIGHT_SENSOR_TSL2561) {
        // Initialize TSL2561 digital sensor
        Serial.println("Initializing TSL2561 light sensor...");

        // Initialize I2C on D2 (GPIO4) and D1 (GPIO5)
        Wire.begin(D2, D1);

        tsl = new Adafruit_TSL2561_Unified(TSL2561_ADDR_FLOAT, 12345);

        if (!tsl->begin()) {
            Serial.println("TSL2561 not detected - check wiring!");
            sensorAvailable = false;
            delete tsl;
            tsl = nullptr;
        } else {
            // Configure sensor
            tsl->enableAutoRange(true);
            tsl->setIntegrationTime(TSL2561_INTEGRATIONTIME_13MS);
            sensorAvailable = true;
            Serial.println("TSL2561 initialized successfully");
        }
    } else if (config.lightSensorType == LIGHT_SENSOR_ANALOG) {
        // Initialize analog sensor
        Serial.println("Initializing analog light sensor...");
        pinMode(ANALOG_LIGHT_PIN, INPUT);
        sensorAvailable = true;
        Serial.println("Analog light sensor initialized");
    } else {
        sensorAvailable = false;
        Serial.println("No light sensor type configured");
    }
}

float lightSensorRead() {
    Config& config = getConfig();

    if (!sensorAvailable || !config.useLightSensor) {
        return -1;
    }

    float reading = 0;

    if (config.lightSensorType == LIGHT_SENSOR_TSL2561 && tsl != nullptr) {
        sensors_event_t event;
        tsl->getEvent(&event);
        reading = event.light;

        if (reading < 0) {
            // Sensor saturated or error
            reading = config.maxLight;
        }
    } else if (config.lightSensorType == LIGHT_SENSOR_ANALOG) {
        reading = analogRead(ANALOG_LIGHT_PIN);
    }

    return reading;
}

uint8_t lightSensorAdjustBrightness() {
    Config& config = getConfig();

    if (!sensorAvailable || !config.useLightSensor) {
        return config.brightness;
    }

    float reading = lightSensorRead();
    uint8_t brightness;

    Serial.printf("Light reading: %.1f", reading);

    if (reading <= config.minLight) {
        brightness = config.minBrightness;  // Use minimum brightness in dark conditions
    } else if (reading >= config.maxLight) {
        brightness = config.maxBrightness;
    } else {
        // Linear interpolation between min and max
        // Guard against division by zero if minLight == maxLight
        float range = (float)(config.maxLight - config.minLight);
        if (range <= 0) range = 1.0f;
        float percent = (reading - config.minLight) / range;
        brightness = percent * (config.maxBrightness - config.minBrightness) + config.minBrightness;
    }

    Serial.printf(" -> brightness: %d\n", brightness);

    ledsSetBrightness(brightness);
    ledsShow();

    return brightness;
}

bool lightSensorIsEnabled() {
    Config& config = getConfig();
    return config.useLightSensor && sensorAvailable;
}

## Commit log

2018-09-01 Updated brightness, LED order, etc.
2018-09-16 Context for capacitor and resistor
2018-09-30 LEDs for second map
2018-12-23 Add PCB files
    [LED Weather Display.brd, LED Weather Display.sch]
2018-12-23 Add enclosure files for 3d printing
    [LED Sectional Body.stl, LED Sectional Cover.stl]
2018-12-27 Various documentation and STL updates.
    [LED Sectional Body.stl]
2018-12-27 Updated STL file.
    [LED Sectional Body.stl]
2019-01-07 Initial code to use an ambient light sensor.
2019-01-07 Light sensor update
2019-01-08 Update sensor code.
2019-01-12 Update for digital light sensor.
    [LED Weather Display.brd, LED Weather Display.sch]
2019-02-12 Update board layouts and kit information in documentation.
    [LED Weather Display.brd, LED Weather Display.sch]
2019-03-03 Default light sensor to false; use preprocessor directives.
2019-03-05 Add support for TSL2561 digital light sensor, and move important settings to top.
2019-03-06 Default light sensor settings to false.
2019-03-06 Fix default data pin.
2019-03-12 Update board layout and doc.
    [LED Weather Display.brd]
2019-04-14 Update PCB files and documentation.
    [LED Weather Display.brd, LED Weather Display.sch]
2019-05-14 Minor change to onboard LED behavior
2019-05-29 Add lightning delay for TSL light sensor.
2019-06-23 PCB traces were incorrect for reset.
    [LED Weather Display.brd, LED Weather Display.sch]
2020-01-21 Update default pin; update pcb layout.
    [LED Sectional.brd, LED Sectional.sch, LED Weather Display.sch]
2020-08-25 Changes to the kit.
    [LED Sectional - BOM.csv, LED Sectional - Centroid.csv, LED Sectional.brd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]
2020-08-29 Add led color indicators.
2020-09-01 .ino files are easier to work with in Arduino IDE.
2025-09-25 Couple of additional changes I forgot to include in the last commit.
2025-12-19 LED Sectional v2.0.0 - Web Configuration & Modern Architecture
    This major release completely rewrites the LED Sectional with a modern
    architecture, browser-based configuration, and improved reliability.
    ## New Features
    ### Web-Based Configuration Tool
    - Browser-based firmware flashing (no software installation required)
    - WiFi configuration via Web Serial
    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
2025-12-19 Fetch firmware from GitHub Releases instead of storing in repo
    - Update manifest.json to fetch from releases/latest/download/led-sectional.bin
    - Remove firmware binaries from git tracking
    - Update CI/CD to upload both versioned and unversioned firmware files
    - Unversioned file enables stable "latest" download URL
2025-12-19 Pin espressif8266 to v2.6.3 to fix FastLED compatibility
    - Downgrade from espressif8266@4.2.1 to @2.6.3
    - Fixes issue where only first LED lights up with newer ESP8266 core
    - Newer cores have WiFi interrupt conflicts with FastLED timing
2025-12-19 Pin FastLED to 3.6.0 for toolchain compatibility
    - FastLED 3.10+ requires C++ features not supported by GCC 4.8.2
    - Pin to 3.6.0 which works with espressif8266@2.6.3 toolchain
2025-12-19 Update web config tool
    🤖 Generated with GitHub Actions
2025-12-19 Fix LED count not updating when airports changed via web
    - Call ledsUpdateCount() when airports array is modified
    - Previously required reboot to see new LED count
    [serial_cmd.cpp]
2025-12-19 Update CONTRIBUTING.md with current library versions and CI/CD
    - Document pinned versions: espressif8266@2.6.3, FastLED@3.6.0
    - Explain why versions are pinned (WiFi/FastLED timing conflicts)
    - Update project structure to show docs/configure
    - Document GitHub Actions workflows for build and deploy
    - Update web app section to reflect automated deployment
2025-12-20 Fix bugs and add runtime dataPin support for old kits
    - Add GPIO 5/14 switch for old kit (D1) vs new kit (D5) compatibility
    - Fix lightning animation memory fragmentation (use fixed-size array)
    - Fix dead code in loop delay logic
    - Fix WiFi SSID buffer safety check
    - Fix serial buffer timeout reset after successful commands
    - Add config validation at save time (brightness, windThreshold, etc.)
    - Fix light sensor to use minBrightness instead of turning off completely
    [leds.cpp, light_sensor.cpp, main.cpp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]
2025-12-20 Add LTNG test code and expand default config to 50 LEDs
    - Add LTNG special airport code for testing lightning animation
    - Expand default config from 8 to 50 LEDs (easier to verify LED strand works)
    - Document special airport codes in CONTRIBUTING.md
2025-12-20 Fix default config: 50 LEDs with KSFO for METAR test
    The compiled-in defaults in config.cpp weren't updated (only data/config.json
    was). Now both match: 5 legend LEDs + KSFO + 44 NULLs = 50 total.
    [config.cpp]
2025-12-20 Show legend colors when no real airports configured
    Previously, if the config only had special codes (VFR, IFR, NULL, etc.),
    the firmware would show error color (cyan) because metarFetch returned
    false. Now it properly displays the legend colors in this case.
    [main.cpp]
2025-12-20 Increase API failure retry interval to 60 seconds
    Reduces retry frequency from 15s to 60s to avoid hammering the API
    if it's having issues.
    [main.cpp]
2025-12-20 Add MQTT integration for Home Assistant control
    - Add MQTT support with Home Assistant auto-discovery
    - Device appears as a light entity with on/off and brightness control
    - Power state persists across reboots
    - MQTT disabled by default, enable in Advanced Settings
    - Add PubSubClient library dependency
    - Add MQTT configuration UI in web tool
    [config.cpp, config.h, leds.cpp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]
2025-12-20 Improve MQTT integration and update documentation
    - Fix entity naming: set entity name to null so it shows as "LED Sectional"
    instead of "LED Sectional LED Sectional"
    - Add LWT (Last Will and Testament) for availability tracking in Home Assistant
    - Make MQTT brightness control maxBrightness when light sensor is active
    - Remove ESP8285 build target (incompatible with current code)
    - Update documentation with Home Assistant integration instructions
    [mqtt.cpp]
2025-12-20 Migrate GitHub Pages to Actions-based deployment
    Replace branch-based Pages deployment with modern GitHub Actions workflow:
    - Add new unified pages.yml workflow that builds Jekyll + web app
    - Remove old deploy.yml that committed build artifacts to repo
    - Remove committed build artifacts from docs/configure/
    - Build artifacts are now created fresh on each deploy
    This fixes the broken Pages deployment after renaming master to main,
    and follows current GitHub best practices.
2025-12-21 Update libraries and fix ESP8266/FastLED compatibility
    - Update espressif8266 platform 2.6.3 → 4.2.1 (Arduino Core 3.1.2)
    - Update FastLED 3.6.0 → 3.10.3
    - Add FastLED.delay(20) before show() and call show() twice for ESP8266 timing
    - Add WiFiManager setWebPortalClientCheck for iOS captive portal fix
    - Change WiFi reset button from GPIO0 to GPIO12 (D6)
    - Fix web UI to only auto-navigate to WiFi tab once per connection
    - Allow legacy import to accept entire .ino file or just the vector
    [config.h, leds.cpp, wifi_manager.cpp]
2025-12-21 Improve web UI workflow and add firmware version tracking
    - Reorder tabs: Firmware first, then WiFi, Airports, Settings, Monitor
    - Add step indicators (1, 2, 3) showing setup progression
    - Show checkmarks when steps are completed
    - Add firmware version reporting from device via get_status
    - Fetch manifest version and compare with device version
    - De-emphasize Firmware tab when device is up-to-date
    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
2025-12-21 Add ledsRefresh() to main loop to self-correct timing glitches
    - Add ledsRefresh() that calls FastLED.show() once per loop iteration
    - Keep ledsShow() with delay+double-show workaround for LED modifications
    - Fixes issue where ESP8266/FastLED timing anomalies persist until next refresh
    [leds.cpp, main.cpp]
2025-12-21 Pin Arduino Core 2.7.4 for FastLED/WiFiManager stability
    - Downgrade espressif8266 platform 4.2.1 → 2.6.3 (Arduino Core 2.7.4)
    - Downgrade FastLED 3.10.3 → 3.7.6 (last version compatible with Core 2.7.4)
    - Downgrade WiFiManager 2.0.17 → 2.0.16-rc.2 (fixes AP mode crash)
    - Remove FASTLED_INTERRUPT_RETRY_COUNT workaround (not needed with Core 2.7.4)
    - Add CLAUDE.md with project context for AI assistance
    - Update CONTRIBUTING.md with detailed version constraint documentation
    - Fix README.md weather update interval (15 min, not 5)
    - Fix CONTRIBUTING.md reset button pin (GPIO12/D6, not GPIO0)
    Core 2.7.4 has more stable interrupt handling for WS2812 LEDs compared to
    Core 3.x, eliminating fi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
2025-12-21 Bug fixes and improvements from code review
    Firmware:
    - Increase MAX_LEDS from 200 to 300
    - Fix light sensor division by zero when minLight == maxLight
    - Add response size limit (150KB) to METAR parsing to prevent OOM
    - Optimize METAR airport string building (O(n) instead of O(n²))
    - Add bounds validation for loopInterval (50ms-60s) and requestInterval (1min-1hr)
    - Clear lightning LEDs when LED count changes to prevent stale indices
    - Add bounds checks in lightning flash loop
    Web:
    - Fix serial command race condition using response queue instead of single resolver
    - Add MAX_AIRPORTS (300) validation with user-visible counter and limit warning
    - Fix version comparison to handle pre-release s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
    [leds.cpp, light_sensor.cpp, metar.cpp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]
2025-12-21 Add wind alternation feature for windy airports
    - New windAlternate setting: alternates between flight category color and yellow
    - Configurable blink interval (1-10 seconds, default 2 seconds)
    - New WBNK special airport code for demonstrating wind blink feature
    - Works for any flight category (VFR, MVFR, IFR, LIFR) when winds exceed threshold
    - Non-blocking animation using millis() timing
2025-12-24 Add LED color order setting to Advanced Settings
    - Add color order dropdown in web UI (RGB, GRB, BRG, RBG, GBR, BGR)
    - Implement software color transformation to avoid IRAM overflow
    - Add colorOrder handler and validation in set_config
    - Common LED strips: RGB for WS2811, GRB for WS2812/WS2812B
    [leds.cpp, serial_cmd.cpp]
2026-04-12 Add configurable no-data color for airports without weather reports
    Airports without valid METAR data previously showed as black (LED off).
    Users can now choose any color via a color picker in Advanced Settings,
    defaulting to black for backwards compatibility.
